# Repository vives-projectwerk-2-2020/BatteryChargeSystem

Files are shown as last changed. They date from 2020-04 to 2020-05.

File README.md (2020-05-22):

# Battery charge system

## Project description

This project is under the MIT license, view it here [MIT License](license.md)

The concept of the this system is to charge some batteries with a solar panel. To supply the whole system.

## Explanation of my roadmap

I first started with the development boards for charging 1 battery with a solar panel. I had 3 boards for use. So I picked the right one. The Adafruit pcb was very interesting for me. And like we all know a Li- Ion battery must be protected when it's fully charged.
After testing everything on the dev pcb's I started designing my own PCB. I used the Eagle software because we're used to it. It wasn't difficult to find the schematics of the dev PCBs. I used those schematics for my base to draw my own PCB.

The duration test of the pcb went very well. I applied a Arduino Uno and a resistor, so i could test if the pcb works fine. There was a current of 50mA through the resistor. If the panel was all day and night outside, one battery was enough. but when the setup wasn't outside, one battery is enough for 2 days. But we need to cover 2 weeks. But this gave me not a correct view of the situation, because we work with sleep modes. And now i have a constant consumption of 50mA. 

The next step was to draw the final schematic of the PCB. Wich is now half the size of the prototype. We made sure the pcb fits in the box we need to use. In this box sit the LoRaWAN antenna and the main pcb with the Nucleo and the batteries too.

## Problems

I hadn't any problems with the PCB draw. Only needed some research for the GND polygoon.

The first problem that came in the game was the Covid-19 outbreak. No more lessons, no more contact with other students. So it wasn't easy to trade the components between some students.

The second problem was that the pcb got down after 3 minutes. When there was no battery attached to the pcb the system worked fine. But once attached, after three minutes, the PCB shuts down.
I did some debugging. The problem was some duplicate functionality. The main IC thought that there was a fully charged battery attached. The MCP 73871 haves all functionality build in that is necessary. So I scrached a wire away so the other ICs (LC05111CMT and MCP73833). The 2 MCP's have the same functionality.
So now the PCB works fine and I could reduce the needed space on the PCB to a minimum.

## Resources

I used the datasheet of the MCP73871 for debugging my PCB. The other documentation was found on the internet. Mostly used for designing my own PCB.

## Battery Charge System

### Description

This panel provide a charge system for charing the batteries via a solar cell.
It seems to be very easy to make this, but actually there comes a lot to play
in the game.
You'll read here how I made this PCB.

#### Develop boards

I first started with some development boards. These PCB's are for sell on the web.
I got 3 boards, so I need to find out witch one was the best for our project.
In this table you'll see the difference between those development boards.

|Feature|Solar Charge Shield V2.2|Adafruit MCP73871|Sparkfun LiPo USB charger|
| ---|:---:|:-----:|:---:|
| **Output disconect** | X  | | |
| **Short circuit protection** | X  | X | |
| **3W output power when connecting battery** | X | | X |
| **Continious charge current**| X  | X | x  |
| **Battery status indication** | X | X | |
| **Micro USB connection** | X | X | X |
| **Load sharing** |  | X | |
| **Temperature monitoring**  |  | X | X |
| **Possible to add extra leds** |  | X |  |
| **Lithium - Polymer batteries** | | X | X |
| **Lithium - Ion batteries** | X | X | X |

I worked together with my classmate Niels to find out with PCB was the best.
We came to a conclusion that the Adafruit board was the best for us.
So the next step was to find oud how it works and how we need to setup the prototype.

##### More information about the development board

##### Specifications

* 3.7V/4.2V Lithium Ion or Lithium Polymer battery charger
* Charge with 5-6V DC, USB or 6V solar panel!
* Automatic charging current tracking for high efficiency use of any wattage
solar panel
* Use any 6V solar panel
* Three color indicator LEDs - Power good, Charging and Done
* Low Battery Indicator (fixed at 3.1V) with LED output on (labeled CHRG)
* Set for 500mA max charge rate, can be adjusted from 50mA up to 1A by soldering
in a resistor
* Will always draw the most current possible from a solar cell- up to the max
charge rate!
* Smart load sharing automatically uses the input power when available, to keep
battery from constantly charging/discharging
* Temperature monitoring of battery by soldering in a 10K NTC thermistor
[thermistor](http://adafru.it/372) (not included) - suggested for outdoor projects
where the battery may get hot (50°C) or cold (0°C).

##### Indicator led's

* The red PWR LED indicates that there is good power connected to the charger.
If this LED is not lit, something is wrong with the power supply
* The orange CHRG LED indicates current charging status. When this LED is lit,
the charger is working to charge up a battery! It also acts as a low battery
indicator (fixed at 3.1V) when no power is connected. So, if you don't have
USB/Solar wired up, when the battery voltage drops below 3.1V, the orange LED
will come on.
* The green DONE LED is pretty easy to understand as well - when it's lit the
battery is charged up! Very handy for when you want to know that everything is done.

##### Extra features

* Load Sharing
* Temperature monitoring
* Adjusting the max charge current
* Adding external LEDs

This was quite easy.
In the picture below you'll see how is set this configuration up.

In the first pic it's the concept of the configuration.

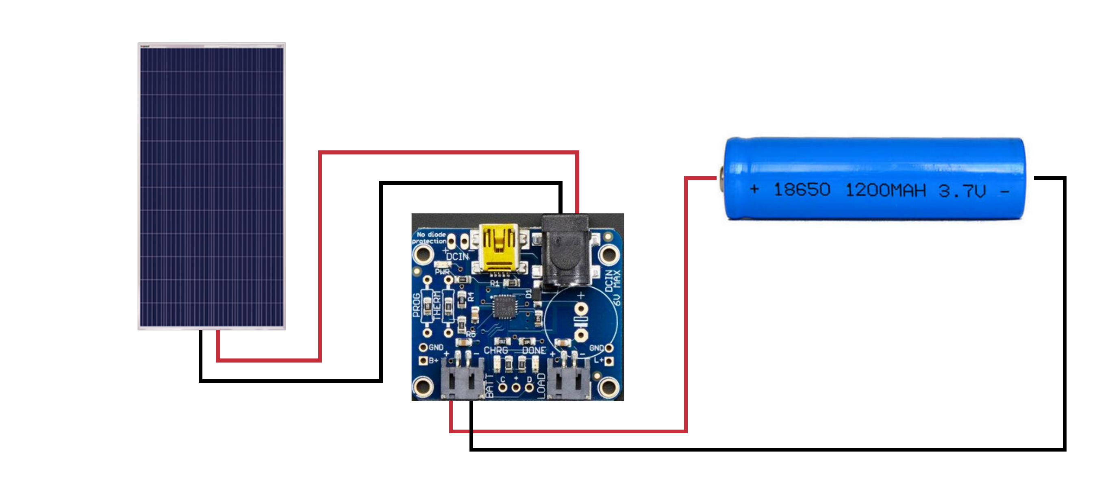
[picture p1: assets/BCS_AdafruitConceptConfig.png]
Concept configuration


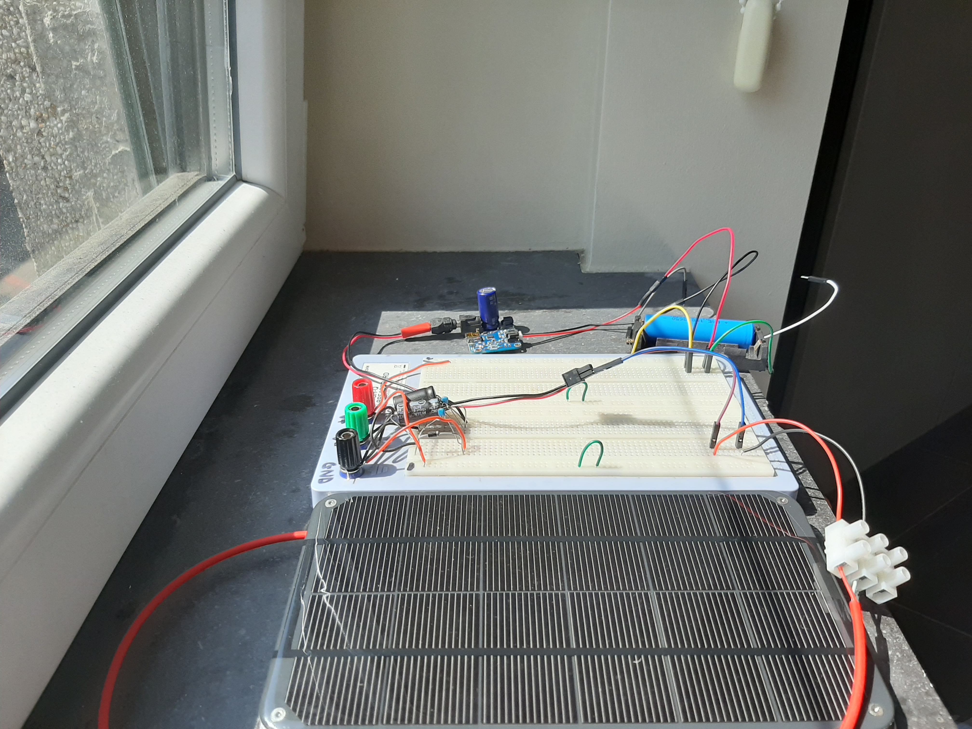
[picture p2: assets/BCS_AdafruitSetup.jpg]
Setup van prototype

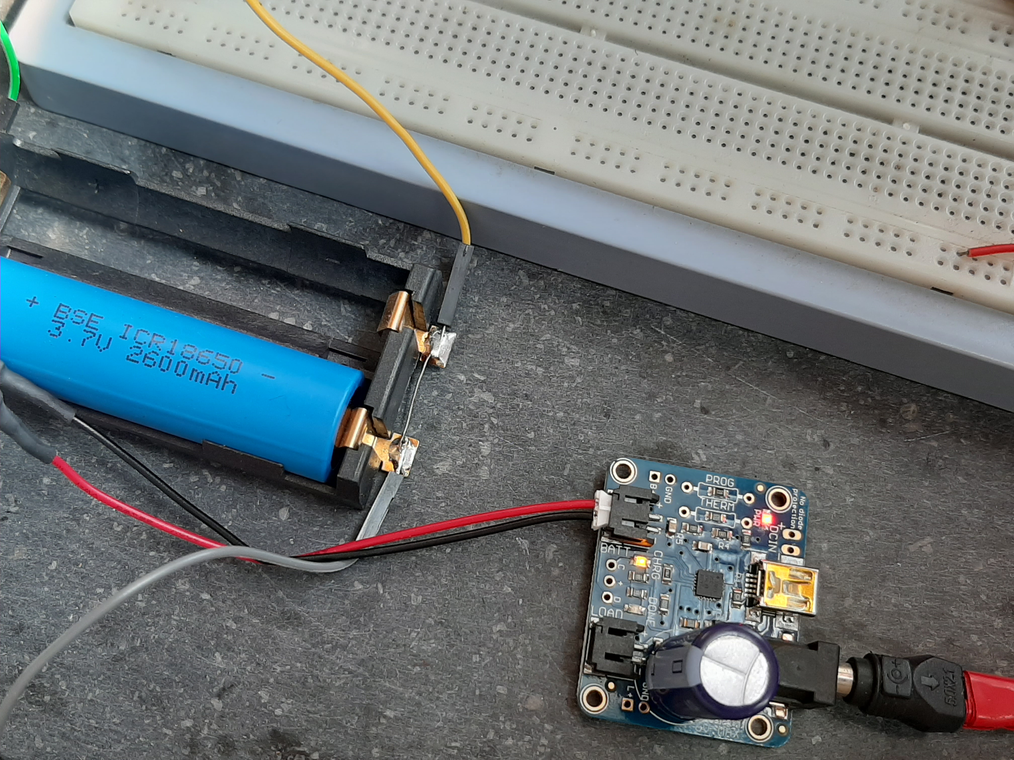
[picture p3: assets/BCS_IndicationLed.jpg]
Indication leds


This system was well tested, so I did some measurements  to see how good it works.
You can see some pictures of the measurements below

##### Charge voltage

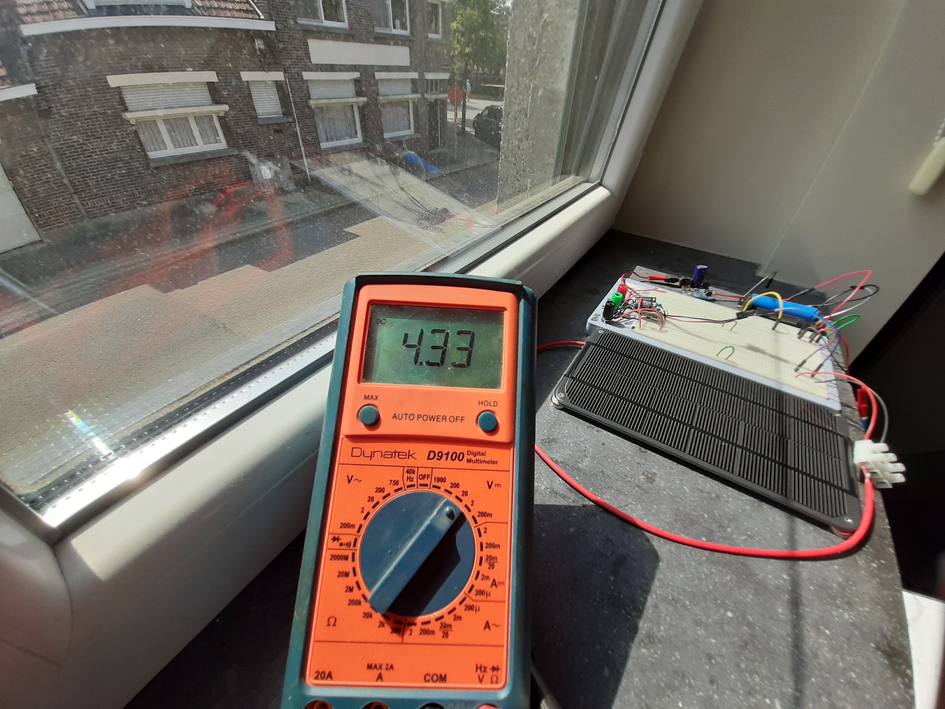
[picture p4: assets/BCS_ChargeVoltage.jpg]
Value of chargevoltage


As we can see, the batteries are supplied with a voltage of 4.3V. A Li-Ion battery
of 3.7V loads until it reaches 4.2V. You can see in the picture of the battery
voltage, that he isn't charged fully. So The charge current is maximum.

##### Charge current

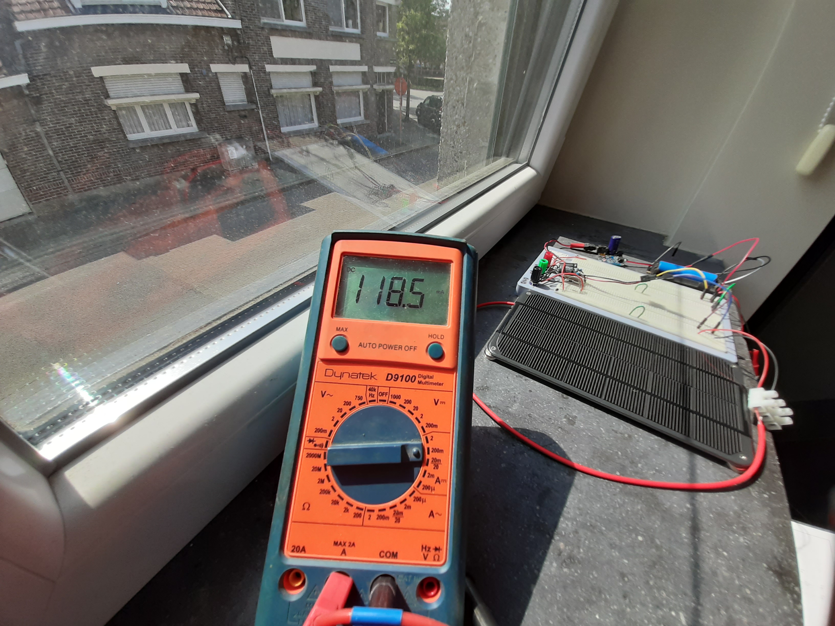
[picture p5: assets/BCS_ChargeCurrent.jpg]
value of charge current


When the battery voltage raises, the charge current will go down. When 4.2V is
reached, the charge current is 0A.
So the current you see on the display, is near maximum.

##### Battery voltage

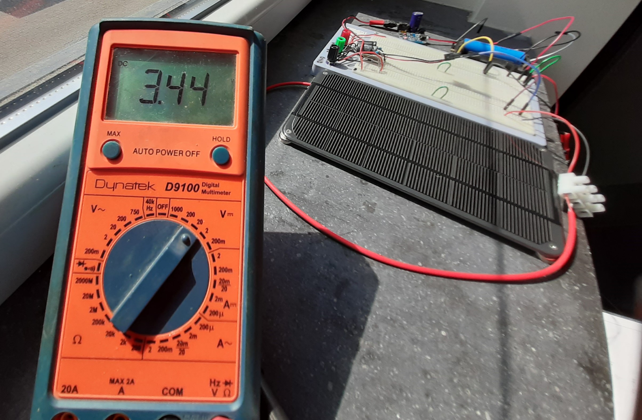
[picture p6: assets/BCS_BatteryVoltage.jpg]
value of battery voltage


The battery voltage is not high, the voltage will go to 4.2V.

##### solar panel voltage

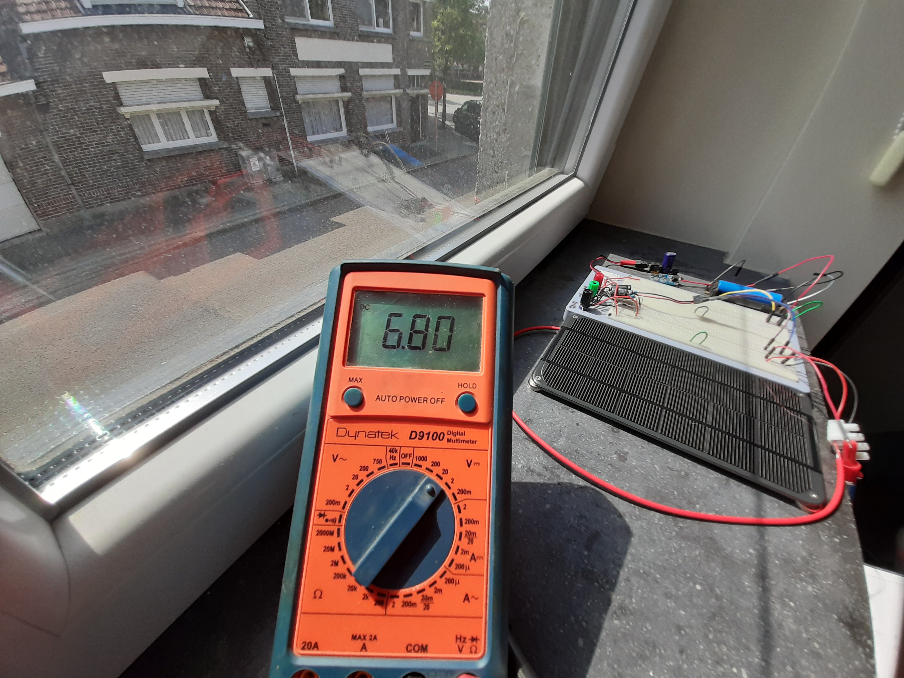
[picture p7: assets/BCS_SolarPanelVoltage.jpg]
value of solar panel voltage


The solar panel provides a voltage of near 7V. This is quite high! In my own
PCB I'll need to protect my main IC from this high voltage.

### Our own design

#### Description of my own design

I used the development boards to look for some inspiration, so I could (easily)
make my own design. I started with a prototype, and I'll explain how this works.

#### Schematic

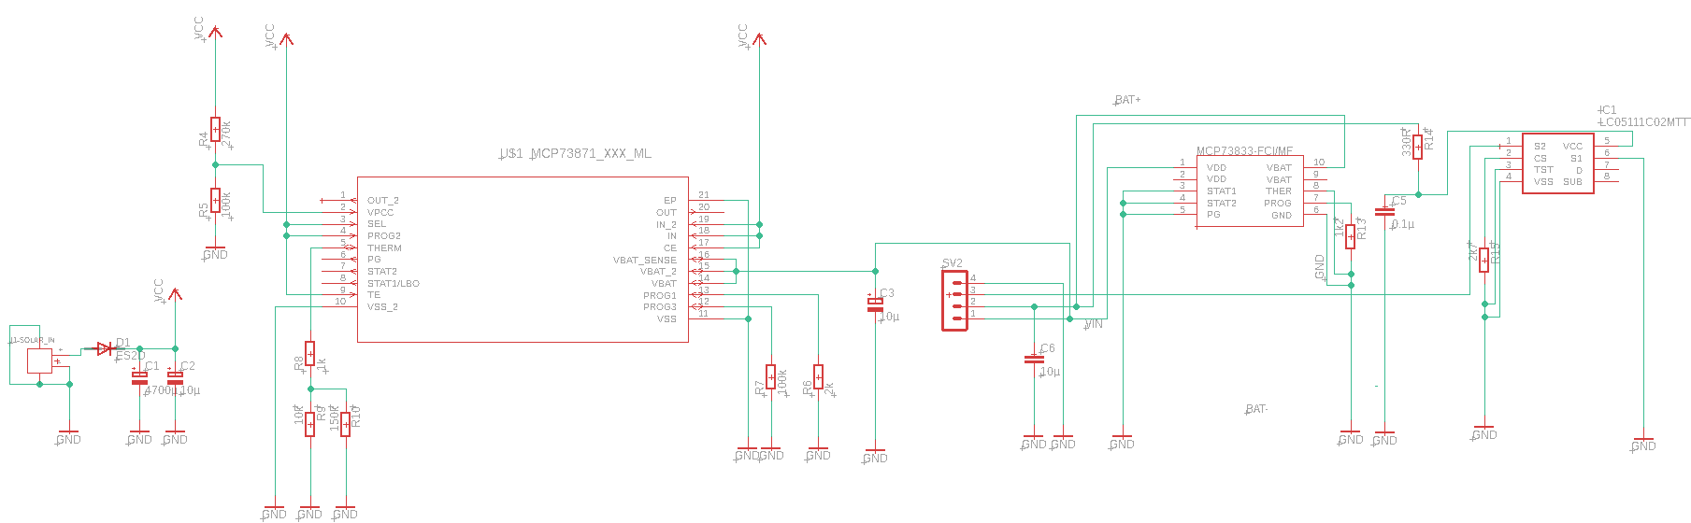
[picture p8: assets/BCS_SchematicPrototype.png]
schematic prototype


##### Description of the schematic

This is the prototype schematic with actually some bugs in it.
The first IC (MCP73871) manages the battery. This was the same IC of the
development board. He'll keep track on the charge current and voltage. When the
battery is charged, the charge current will be 0 because this IC will drop it down.
There is also a possibility to get some information via the PG, STAT1, STAT2 pins.
These aren't provided here, but in the final PCB it does. This IC takes the
voltage from the solar panel and have's an output of 4.3V.

The second IC is a battery management IC too, this will cause problems. You'll
see in the final PCB that this IC is deleted. In first place I thought that it
was necessary to provide a protection circuit for the battery. But the MCP73871
haves already this functionality. So I will discuss my problems later in this
document, and will explain there what went wrong.

The other components are some interfacing for these IC's.

#### Board

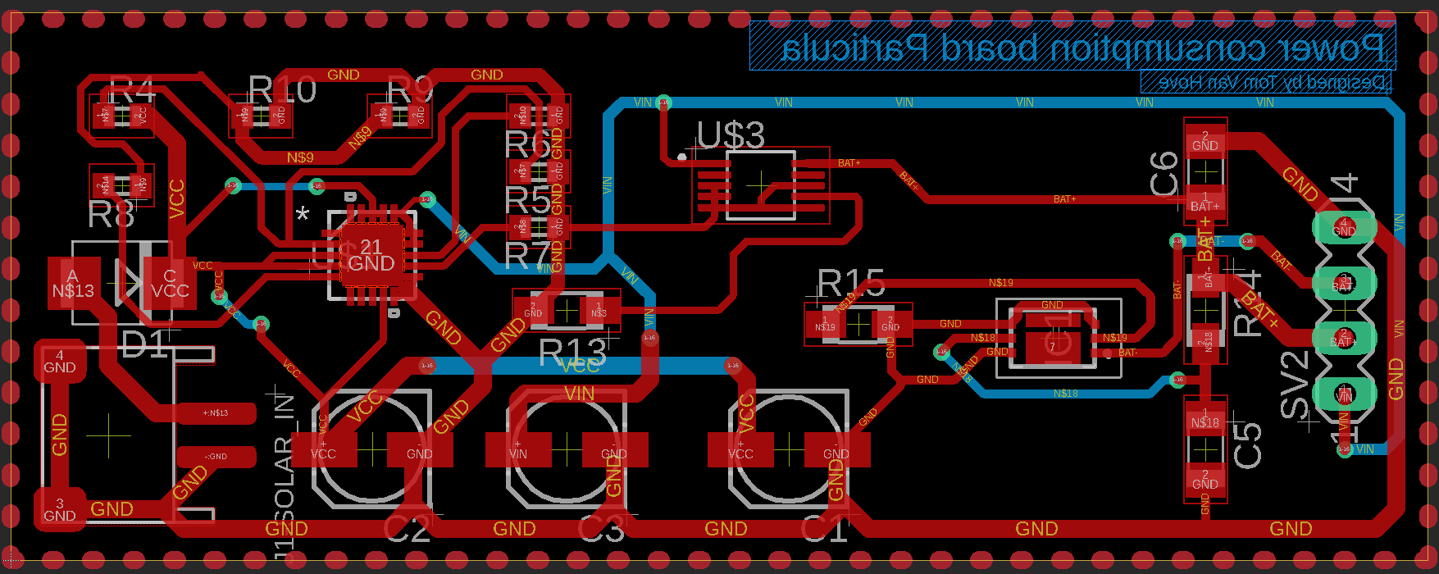
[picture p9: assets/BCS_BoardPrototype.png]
board prototype

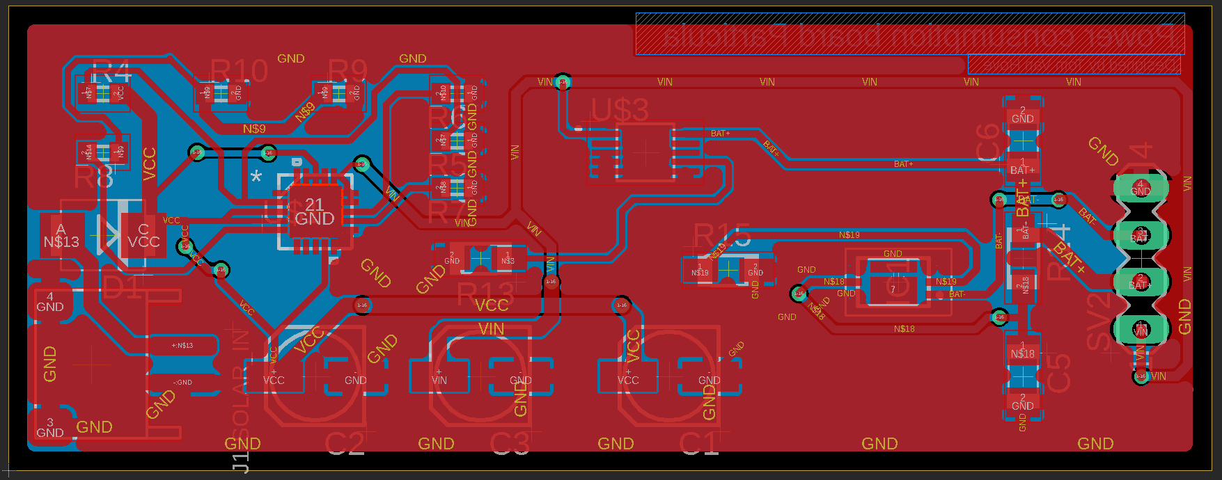
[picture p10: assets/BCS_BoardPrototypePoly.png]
board prototype with polygon


##### Description of the board

The next step was to draw the board. This is quite easy. The first picture is
the schematic witout polygon, the second one is the PCB with polygon. We let
these PCB's made in Japan. Via [JLCPCB](http://JLCPCB.com). Then we bought our
components by Farnell for fast shipping. When we got all components and boards,
we could start soldering. Me and my colleagues are used to solder, so this
wasn't any problem for us.

In this pic you'll see the unsoldered and soldered PCB

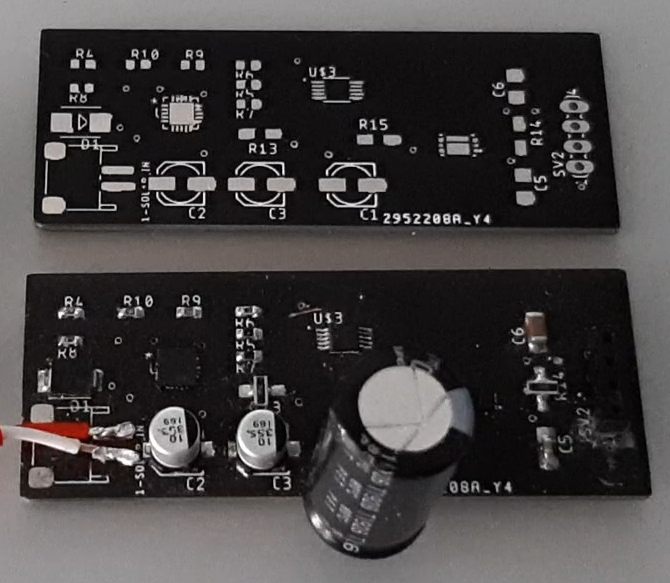
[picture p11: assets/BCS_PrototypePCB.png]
manufactured pcb


#### Description of the final design

You can find here the link to the GitHub repo of the schematic, board and partlist.
[GitHub repo final design](https://github.com/vives-projectwerk-2-2020/FinalSolarChargeSystem)

#### Final Schematic

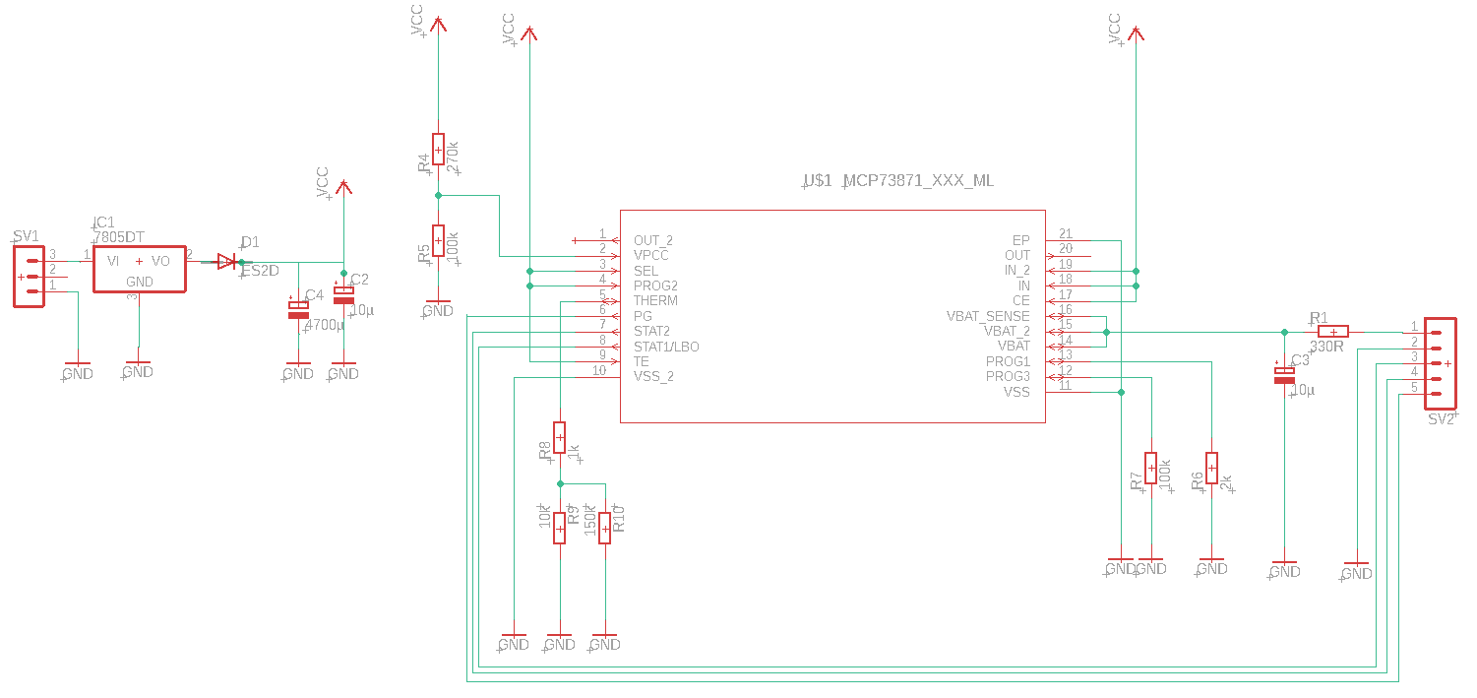
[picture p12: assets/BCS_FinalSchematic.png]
final schematic


##### Description of the final schematic

As you can see here, the other IC's are removed. This because they have the same
functionality as the MCP73871. I placed a voltage regulator before the IC, this
is because you can have a max voltage of 6V on the IC, and the solar panel
provides 6+V.
Here I brought the STAT1, STAT2 and PG pins outside, so we can manage the battery
on the Nucleo.
This PCB will fit on the main PCB (See Niels his documents).

#### Final Board

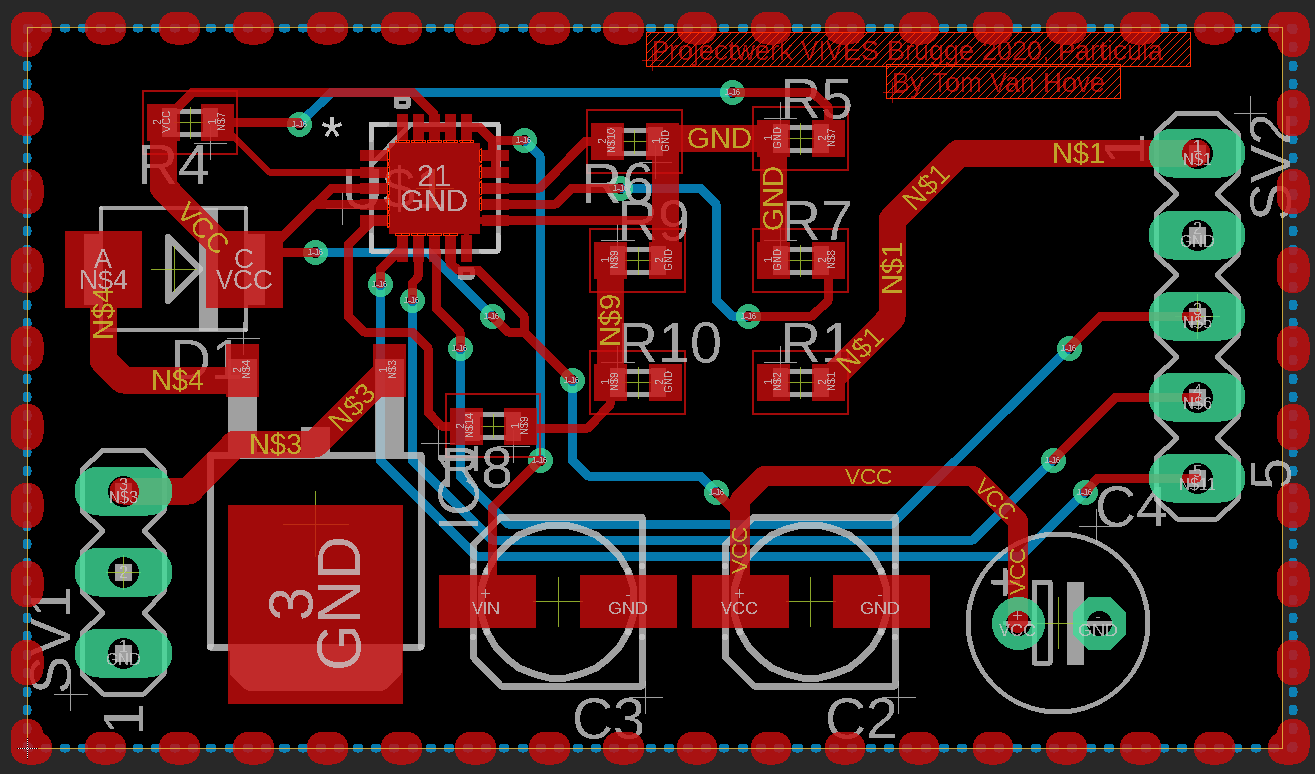
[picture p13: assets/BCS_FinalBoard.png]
final board

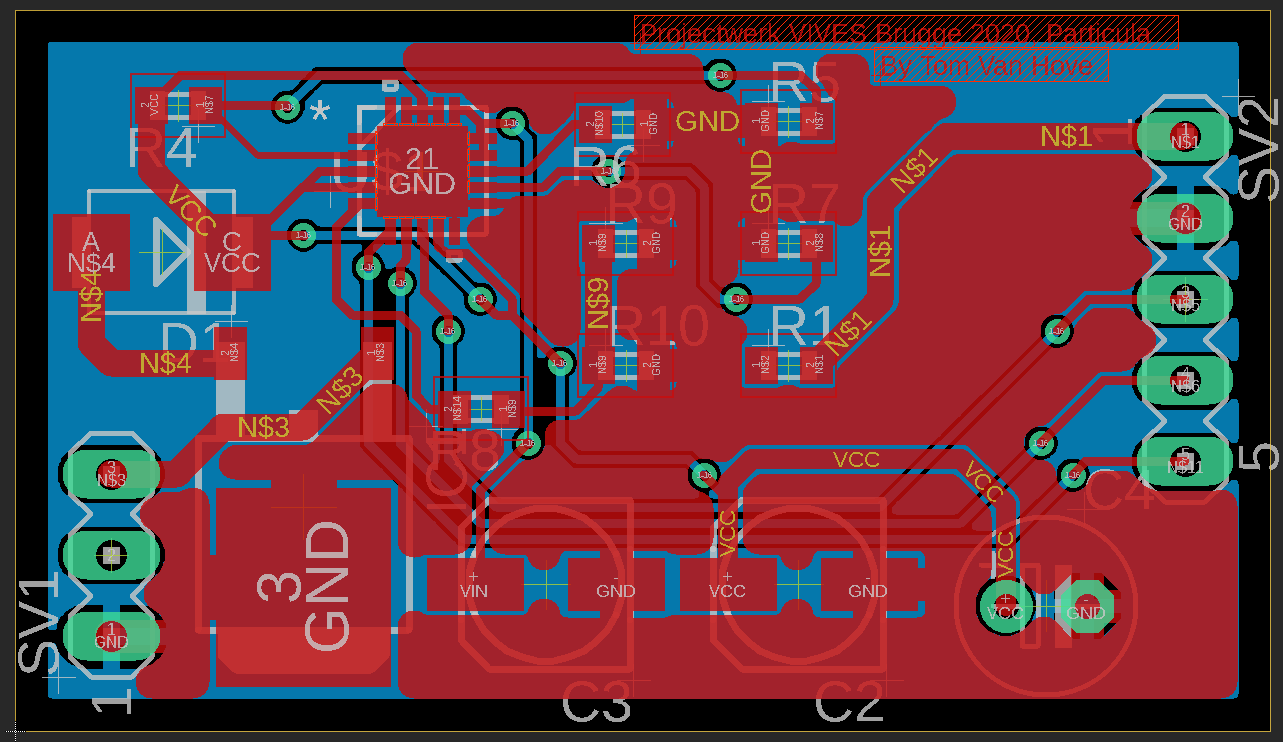
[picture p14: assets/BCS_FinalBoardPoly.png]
final board with polygon


##### Description of the final Board

There is not so much to tell about it, here to, just draw the wires.
We couldn't order these PCB's because of the COVID-19 pandemic.

### Tests

When we had the prototype PCB, we soldered them, and then we need to test if they
really work.

When I tested the PCB without a battery connected, the charge voltage was 4.2V.
This was really good, that worked. But when I attached a battery, the system
falls down after 2 minutes. So is started looking for the problem. And as you
could see, there is a difference between the prototype PCB and the final PCB.
1 IC in stead of 3. This was because the MCP73871 have same functionality of all
those other IC's. So I don't need them. What was the source of the problem? Well,
the MCP73871 checked the battery status, but he actually checked the MCP83833
and this IC wasn't a battery, so the MCP73871 shuts down because he thought that
te battery was fully charged.
When scratching away the wire tot the MCP83833, the PCB worked like it need to be!

After this, is started a duration test. I made a setup with a Arduino UNO to
have a current taken away from the battery.
The charge PCB was still connected to the batteries.
The setup have been outside for 3 - 4 weeks, day and night.
In the picture below, you'll see the setup I made.

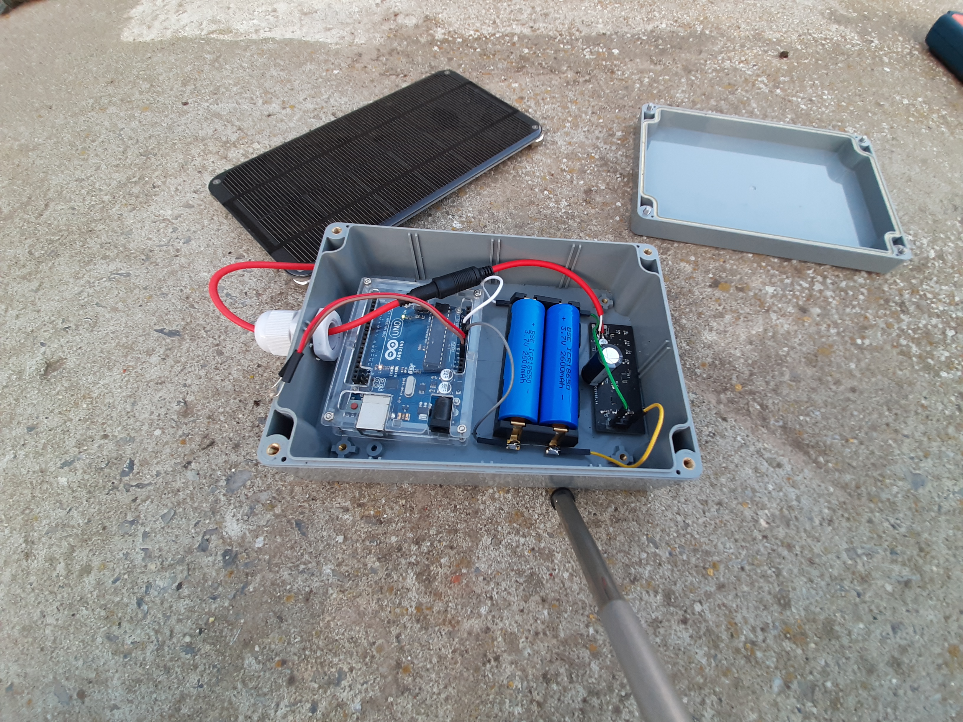
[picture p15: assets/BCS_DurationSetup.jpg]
duration setup

outdoor config

I went daily for a measurement of the PCB. I measured the voltage of the solar
panel, IC input, IC output, battery voltage and charge current.
|Measurement | Value |
|---|---|
|Solar panel |6,8V |
|IC input |5V |
|IC output |4,2V |
|Battery voltage|3V - 4.2V |
|charge current |0mA - 100mA |

The charge current depends on the weather. When it is a nice day, you'll reach
higher current measurements. The charge current depends on the battery voltage
too. When the battery voltage reaches 4.2V, the current will drop town to 0.

How I did these measurements, can be found in my Youtube video.

### Links

* [MCP73871 datasheet](http://adafru.it/aMO)
* [Fritzing object in Adafruit Fritzing library](http://adafru.it/aP3)
* [EagleCAD Board / Layout & Schematic files on Github](http://adafru.it/aMP)

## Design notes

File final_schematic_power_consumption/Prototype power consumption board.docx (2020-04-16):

# Prototype power consumption board

# Schematic

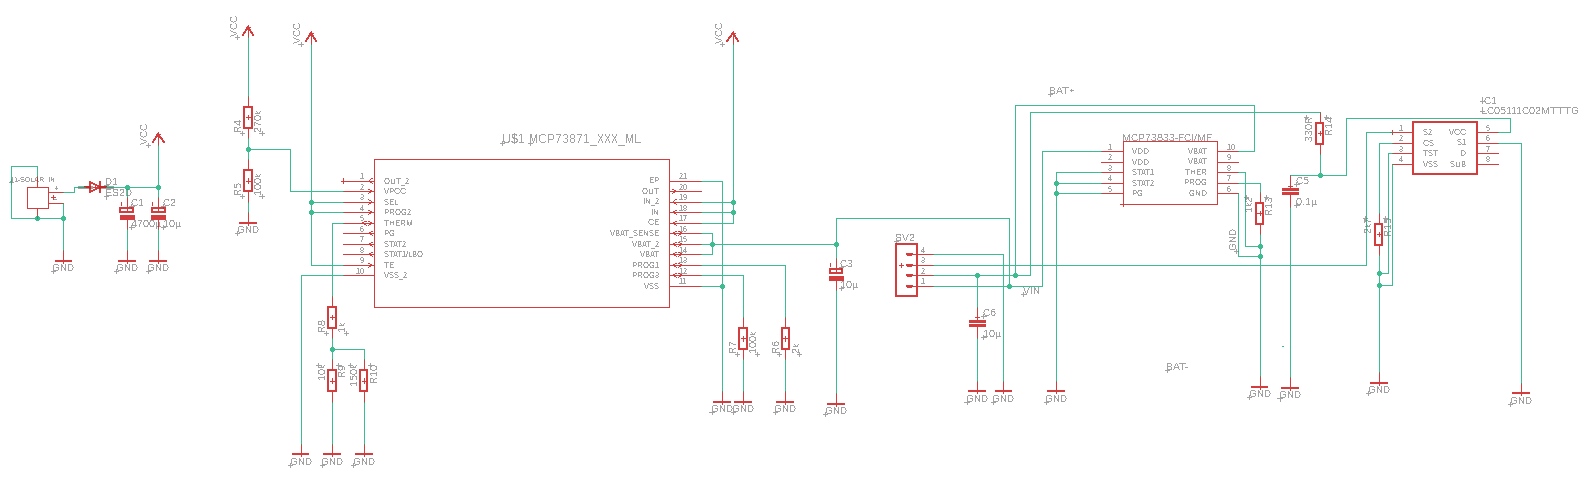
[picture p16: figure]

# Board

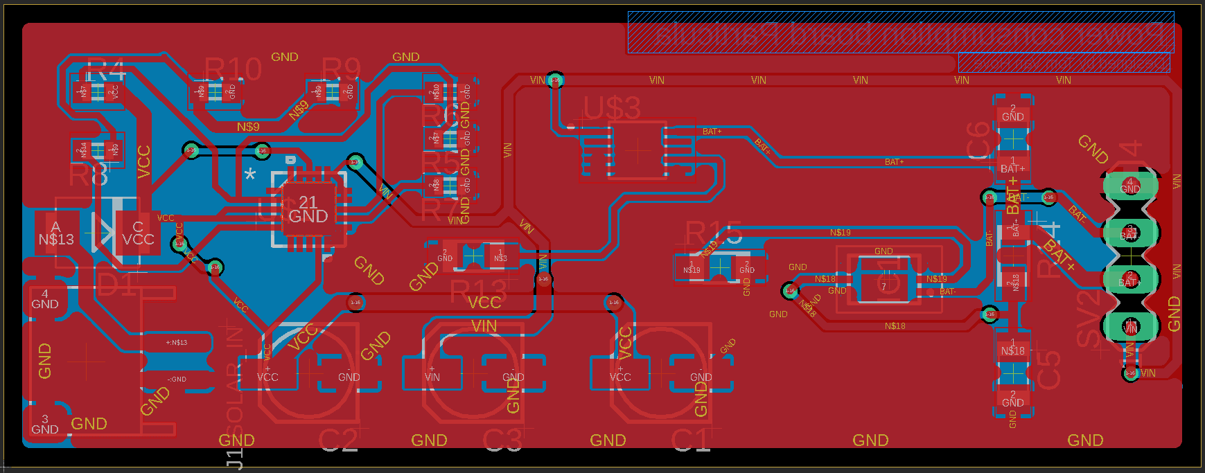
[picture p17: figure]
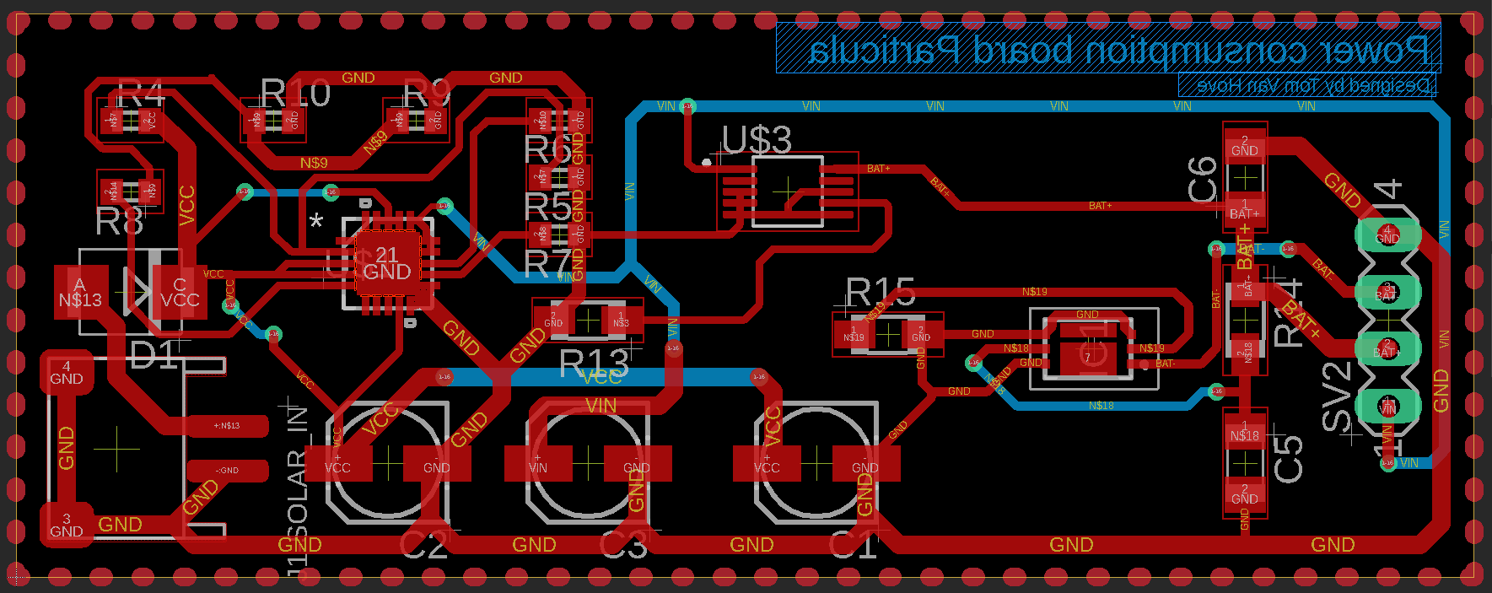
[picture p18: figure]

# Partlist FARNELL

Part | Value | FARNELL NR
C1 | 4700Âµ | 2346507
C2 | 10Âµ | 9697012
C3 | 10Âµ | 9697012
C5 | 0.1Âµ | 2211074
C6 | 10Âµ | 1907353
D1 | ES2D | 1467491
IC1 | LC05111C02MTTTG | 2728216
J1-SOLAR_IN
R4 | 270k | 2447313
R5 | 100k | 1692517
R6 | 2k | 2447319
R7 | 100k | 1692517
R8 | 1k | 9238484
R9 | 10k | 2861870
R10 | 150k | 2447254
R13 | 1k2 | 3254959
R14 | 330R | 3254970
R15 | 2k7 | 3254908
SV2 | | 1667510
U$1 | MCP73871_XXX_ML | 1642489
U$3 | MCP73833-FCI/MF | 1605576

# Recommandations

## PCB order

The ordering of the PCBs went very well. JLCPCB is an good site with fast shipping. The quality of them are very nice!

## Component order

We worked with Farnell because their fast shipping. Everything went well, all components are in stock and they were delivered very soon. But in multiple packets.

## Soldering

The soldering went great. We used only SMD. With the soldering station of VIVES it went very good! We used very small components because of available space on our PCB and we need to fit 3 PCBs in 1 single box with batteries.

I can make my PCB more smaller and that’s the next step after testing and debugging.

One mistake we made with the component order, we didn’t order an FLUX CLEANER so our PCB is a bit dirty right now. The final PCB will be clean.

## Testing

I tested the PCB only with a solarpanell and without batteries. And I got a voltage measure of 4.2V what is very nice!

After that step I loaded some batteries and the PCB stop charging when the batteries are 3.7V loaded. I’m not sure that that would be enough for feeding the NUCLEO and other hardware. Maybe I can place 2 batteries serial, but my pcb won’t work anymore. I can place them parallel too, for more capacity.

After charging the batteries, I discharged them with an ventilator (just a consumer, it could be anything). The ventilator worked 22 hours, non stop.

After this I recharged 1 battery …

TODO

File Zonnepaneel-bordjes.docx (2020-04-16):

Solar Charger Shield V2.2

1. Features:
- Output Disconnect
- Short circuit protection
- 3W Output Power when connecting battery
- Continuous Charge Current Up to 900mA
- Battery status indication ( Red : Charging , Green: Charged )
- Micro-USB Connector
2. Specification
- Battery input voltage: 3.0~4.5V
- USB input voltage: 4.75~5.25V
- Solar input voltage: 4.8~6V
- Maximum Output Power(with battery): 3W(600mA@5V)
- Ripple voltage: <100mV @ 500mA
- Dimensions: 68*53mm
3. Applications
- Wireless sensor unit
- Solar charge
- Tweet-a-volt-arduino
4. Caution
- The solar charger shield is designed to protect any potential short circuit. However care must be taken to avoid any such situations.
- The solar shield should not be operated at voltages greater than 5V

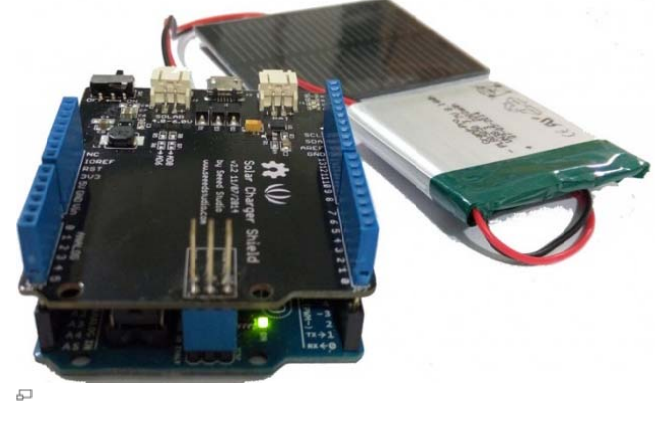
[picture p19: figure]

USB, DC & Solar Lipoly Charger

1. Specifications
- 3.7V/4.2V Lithium Ion or Lithium Polymer battery charger
- Charge with 5-6V DC, USB or 6V solar panel!
- Automatic charging current tracking for high efficiency use of any wattage solar panel
- Use any 6V solar panel
- Three color indicator LEDs - Power good, Charging and Done
- Low Battery Indicator (fixed at 3.1V) with LED output on (labeled CHRG)
- Set for 500mA max charge rate, can be adjusted from 50mA up to 1A by soldering in a resistor
- Will always draw the most current possible from a solar cell- up to the max charge rate!
- Smart load sharing automatically uses the input power when available, to keep battery from constantly charging/discharging
- Temperature monitoring of battery by soldering in a 10K NTC thermistor (http://adafru.it/372) (not included) - suggested for outdoor projects where the battery may get hot (50°C) or cold (0°C).
2. Installing the Capacitor
- This capacitor is necessary to stabilize the panel a little, and since we're going to charge with a lot of current, the capacitor needs to be pretty big.
3. USB & DC Charging
- Of course, sometimes is just really dark out and you can't solar charger, so there's a USB port on the board as well.
- Use any mini-B cable to plug in and charge.
4. Indicator LEDs
- The red PWR LED indicates that there is good power connected to the charger. If this LED is not lit, something is wrong with the power supply
- The orange CHRG LED indicates current charging status. When this LED is lit, the charger is working to charge up a battery! It also acts as a low battery indicator (fixed at 3.1V) when no power is connected. So, if you don't have USB/Solar wired up, when the battery voltage drops below 3.1V, the orange LED will come on.
- The green DONE LED is pretty easy to understand as well - when it's lit the battery is charged up! Very handy for when you want to know that everything is done.
5. Extra features
- Load Sharing
- Temperature monitoring
- Adjusting the max charge current
- Adding external LEDs
6. Files
- MCP73871 datasheet (http://adafru.it/aMO)
- Fritzing object in Adafruit Fritzing library (http://adafru.it/aP3)
- EagleCAD Board / Layout & Schematic files on Github (http://adafru.it/aMP)

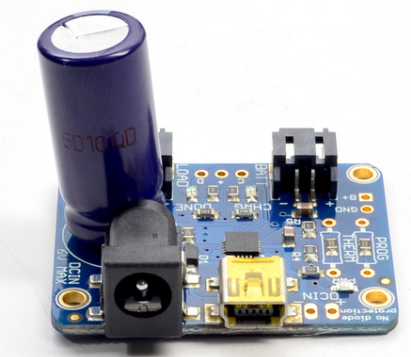
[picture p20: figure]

Single-cell LiPo MPPT charger

1. Features
- Input Supply Voltage Regulation Loop for Peak Power Tracking in (MPPT) Solar Applications
- Wide Input Voltage Range: 4.95V to 32V (40V Abs Max)
- Programmable Charge Rate Up to 2A
- User Selectable Termination: C/10 or On-Board Termination Timer
- Resistor Programmable Float Voltage Up to 14.4V Accommodates Li-Ion/Polymer, LiFePO4, SLA Chemistries
- No VIN Blocking Diode Required for Battery Voltages ≤ 4.2V
- 1MHz Fixed Frequency
- 0.5% Float Voltage Reference Accuracy
- 5% Charge Current Accuracy
- 2.5% C/10 Detection Accuracy
- Binary-Coded Open-Collector Status Pins
- 3mm × 3mm DFN12 or MSOP-12 Packages
2. Description
- The LT®3652 is a complete monolithic step-down battery charger that operates over a 4.95V to 32V input voltage range.
- The LT3652 provides a constant-current/ constant-voltage charge characteristic, with maximum charge current externally programmable up to 2A.
- The charger employs a 3.3V fl oat voltage feedback reference, so any desired battery fl oat voltage up to 14.4V can be programmed with a resistor divider.
- The LT3652 employs an input voltage regulation loop, which reduces charge current if the input voltage falls below a programmed level, set with a resistor divider.
- When the LT3652 is powered by a solar panel, the input regulation loop is used to maintain the panel at peak output power.
- The LT3652 can be confi gured to terminate charging when charge current falls below 1/10 of the programmed maximum (C/10).
- Once charging is terminated, the LT3652 enters a low-current (85μA) standby mode.
- An auto-recharge feature starts a new charging cycle if the battery voltage falls 2.5% below the programmed float voltage.
- An auto-recharge feature starts a new charging cycle if the battery voltage falls 2.5% below the programmed fl oat voltage.
- The LT3652 also contains a programmable safety timer, used to terminate charging after a desired time is reached.
- This allows top-off charging at currents less than C/10
3. Absolute maximum ratings

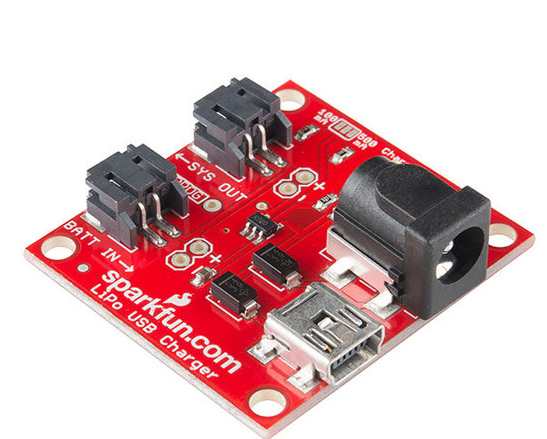
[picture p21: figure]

Differences

| Solar Charger Shield V2.2 | USB, DC & Solar Lipoly Charger | Single-cell LiPo MPPT charger
Output Disconnect | X
Short circuit protection | X | x
3W Output Power when connecting battery | X | | x
Continuous Charge Current Up to 500mA -900mA | X | X (when soldering extra resistor) | x
Battery status indication ( Red : Charging , Green: Charged ) | X | x
Micro-USB Connector | X | x | x
Load sharing | | x
Temperature monitoring | | x | x
Posibillity to ad external LEDs | | x
Lithium-Polymer batteries | | x | X
Lithium-Ion batteries | x | | x

Datasheets

https://cdn-learn.adafruit.com/downloads/pdf/usb-dc-and-solar-lipoly-charger.pdf

https://static.chipdip.ru/lib/164/DOC001164903.pdf

http://cdn.sparkfun.com/datasheets/Prototyping/LT3652.pdf

https://www.distrelec.be/Web/Downloads/_t/ds/Adafruit_390_eng_tds.pdf?pid=30091214

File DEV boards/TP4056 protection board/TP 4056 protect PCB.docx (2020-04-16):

# TP 4056 - protect PCB

# Specificaties

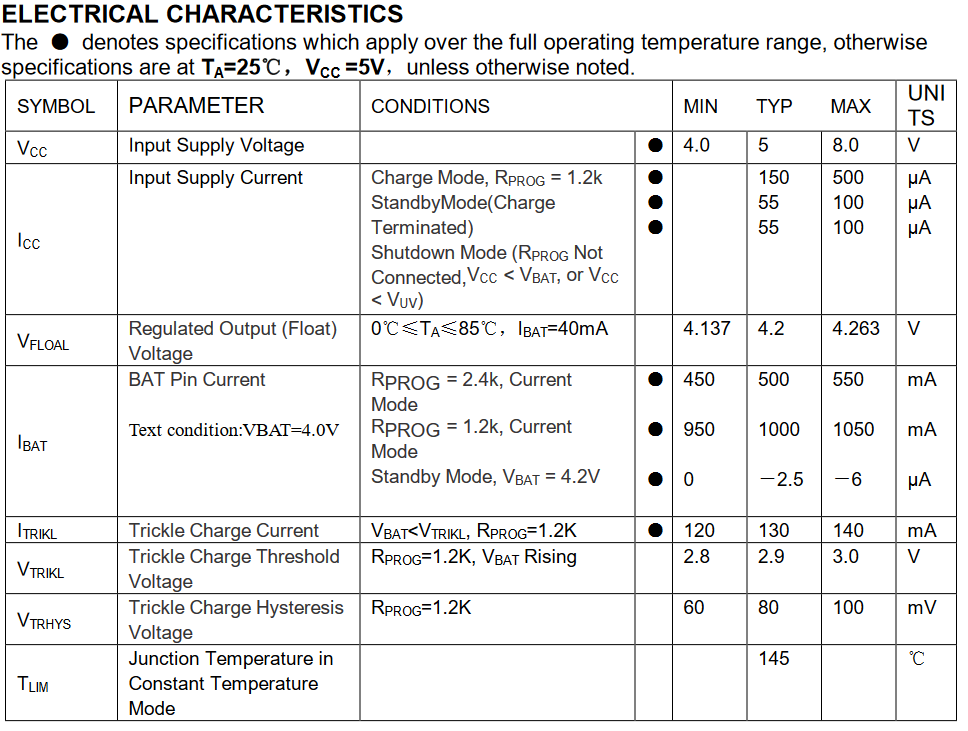
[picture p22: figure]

# Doel

Bescherming batterij tegen overspanning. Als de batterij vol geladen is, dan zal deze schakeling de kring onderbreken.

# Werking

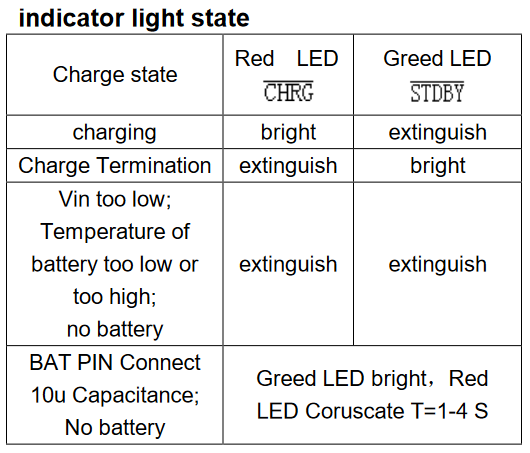
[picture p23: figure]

Als de batterij aan het opladen is, dan zal de rode led gaan branden op de PCB. Als de batterij volgeladen is dan gaat de groene led oplichten.

Stel er hangt geen batterij aan, of de ingangsspanning is te laag, temperatuur te hoog of te laag is.

Bij het opladen met het zonnepanneel, hebben we een laadstroom van rond de 50mA. Kiezen we voor een USB gevoede lading, spreken we over een laadstroom van rond de 150mA. Resultaat, via USB zal de batterij veel sneller geladen kunnen worden.

Als de spanning van de batterij stijgt, dan zal de laadstroom dalen, tot op 0, waarbij de groene led dan gaat branden.

# Schematische voorstelling

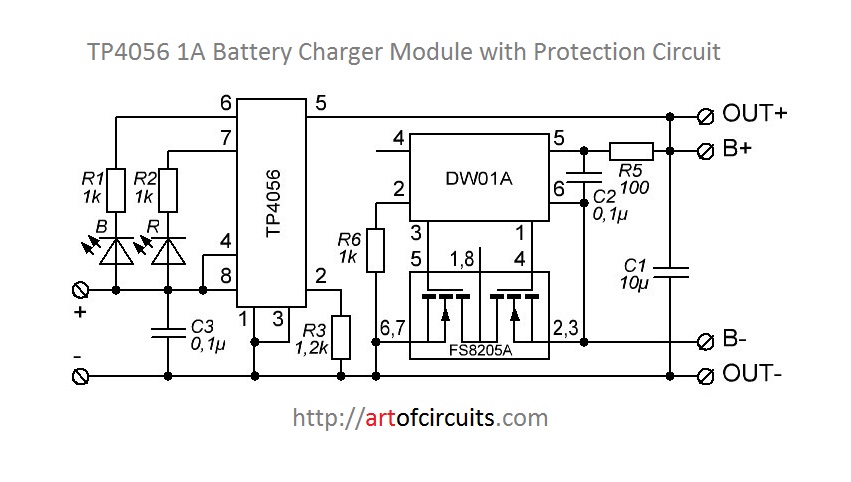
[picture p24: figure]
Schema

## DW01A

https://www.ic-fortune.com/upload/Download/DW01x-DS-17_EN_53550.pdf

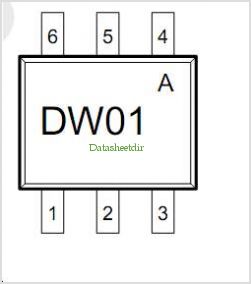
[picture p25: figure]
DW01A pinout,Pin out

## TP4056

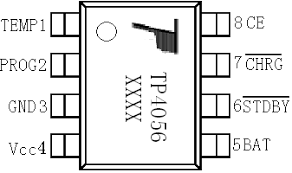
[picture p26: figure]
C:\Users\Tom\AppData\Local\Microsoft\Windows\INetCache\Content.MSO\A78E72FA.tmp

## FS8205A

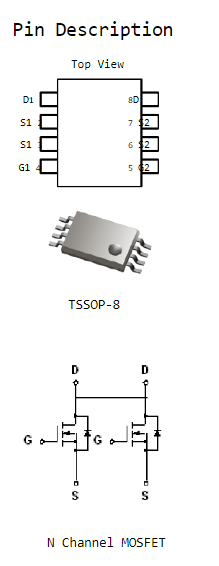
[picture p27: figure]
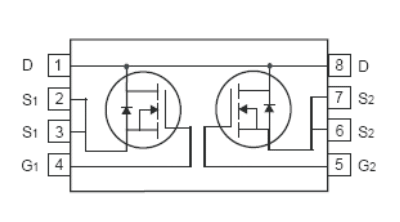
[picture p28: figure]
Afbeeldingsresultaat voor 8205a pinout
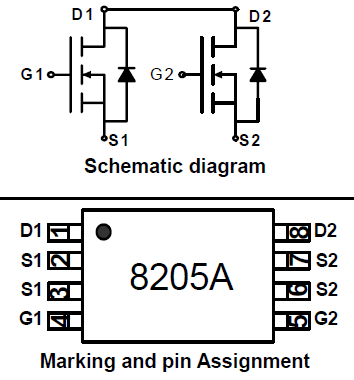
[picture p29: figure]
Afbeeldingsresultaat voor 8205a pinout

# Aansluiting

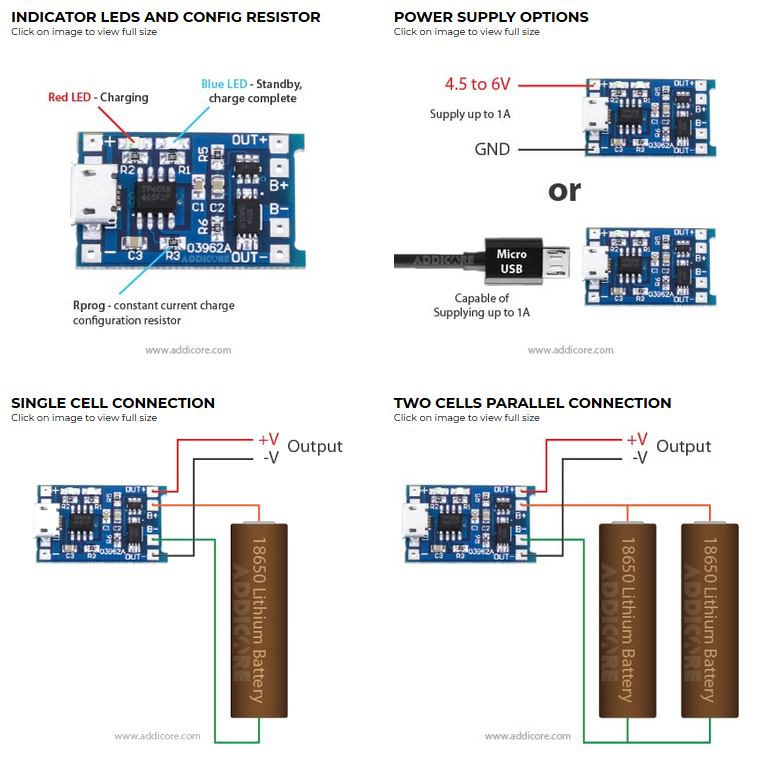
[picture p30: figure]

# Interessante links

https://dlnmh9ip6v2uc.cloudfront.net/datasheets/Prototyping/TP4056.pdf

https://www.makerlab-electronics.com/product/tp4056-5v-1a-lithium-battery-charging-with-protection-micro-usb/

https://www.addicore.com/TP4056-Charger-and-Protection-Module-p/ad310.htm

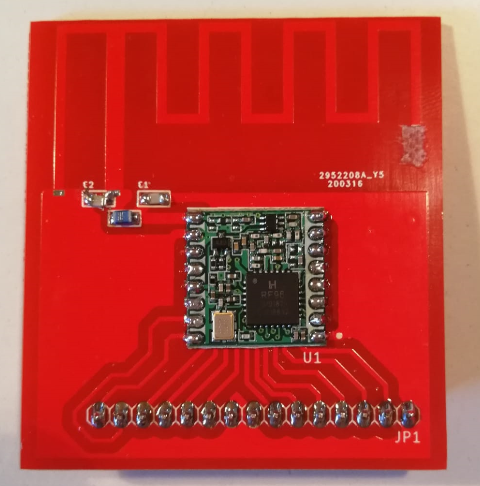
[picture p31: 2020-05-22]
assets/Antenna_board.png

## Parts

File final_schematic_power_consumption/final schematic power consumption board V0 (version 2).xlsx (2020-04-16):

Part | Value | Device | Package | Description
C1 | 4700Âµ | CPOL-EU153CLV-0505 | 153CLV-0505 | POLARIZED CAPACITOR, European symbol | 2346507 | 3 | https://be.farnell.com/rubycon/16pk4700mefc12-5x25/cap-4700-f-16v-20/dp/2346507
C2 | 10Âµ | CPOL-EU153CLV-0505 | 153CLV-0505 | POLARIZED CAPACITOR, European symbol | 9697012 |  | https://be.farnell.com/panasonic/eee1va100sr/cap-10-f-35v-radial-smd/dp/9697012
C3 | 10Âµ | CPOL-EU153CLV-0505 | 153CLV-0505 | POLARIZED CAPACITOR, European symbol | 9697012 |  | https://be.farnell.com/panasonic/eee1va100sr/cap-10-f-35v-radial-smd/dp/9697012
C5 | 0.1Âµ | C-EUC1206 | C1206 | CAPACITOR, European symbol | 2211074 |  | https://be.farnell.com/tdk/cga5l2c0g1h104j160aa/cap-0-1-f-50v-5-c0g-np0-1206/dp/2211074
C6 | 10Âµ | C-EUC1206 | C1206 | CAPACITOR, European symbol | 1907353 |  | https://be.farnell.com/tdk/c3216x7r1c106k160ac/cap-10-f-16v-10-x7r-1206/dp/1907353
D1 | ES2D | ES2D | SMB | DIODE | 1467491 |  | https://be.farnell.com/on-semiconductor/es2d/diode-fast-2a-200v-smd-do-214/dp/1467491?st=ES2D
IC1 | LC05111C02MTTTG | LC05111C02MTTTG | LC05111C02MTTTG | Battery Management 1 CELL LIB PROTECTION IC | 2728216 |  | https://be.farnell.com/on-semiconductor/lc05111c02mtttg/over-current-protector-li-ion/dp/2728216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
J1-SOLAR_IN |  | CONN-HEADER-SMD-PH-SIDE-(2P-2.0MM) | HW2-SMD-2.0-90D | 320110026
R4 | 270k | R-EU_R0603 | R0603 | RESISTOR, European symbol | 2447313 |  | https://be.farnell.com/multicomp/mcwr06x2703ftl/res-270k-1-0-1w-thick-film/dp/2447313
R5 | 100k | R-EU_R0603 | R0603 | RESISTOR, European symbol | 1692517 |  | https://be.farnell.com/vishay/crcw0603100kjnea/res-100k-5-0-1w-0603-thick-film/dp/1692517
R6 | 2k | R-EU_R0603 | R0603 | RESISTOR, European symbol | 2447319 |  | https://be.farnell.com/multicomp/mcwr06x2001ftl/res-2k-1-0-1w-0603-thick-film/dp/2447319
R7 | 100k | R-EU_R0603 | R0603 | RESISTOR, European symbol | 1692517 |  | https://be.farnell.com/vishay/crcw0603100kjnea/res-100k-5-0-1w-0603-thick-film/dp/1692517
R8 | 1k | R-EU_R0603 | R0603 | RESISTOR, European symbol | 9238484 |  | https://be.farnell.com/yageo/rc0603fr-071kl/res-1k-1-0-1w-0603-thick-film/dp/9238484
R9 | 10k | R-EU_R0603 | R0603 | RESISTOR, European symbol | 2861870 |  | https://be.farnell.com/te-connectivity/crgcq0603j10k/res-10k-5-0603-thick-film/dp/2861870
R10 | 150k | R-EU_R0603 | R0603 | RESISTOR, European symbol | 2447254 |  | https://be.farnell.com/multicomp/mcwr06x1503ftl/res-150k-1-0-1w-thick-film/dp/2447254
R13 | 1k2 | R-EU_R1206W | R1206W | RESISTOR, European symbol | 3254959 |  | https://be.farnell.com/rohm/ltr18ezpj122/res-1k2-5-0-75w-1206-thick-film/dp/3254959
R14 | 330R | R-EU_R1206W | R1206W | RESISTOR, European symbol | 3254970 |  | https://be.farnell.com/rohm/ltr18ezpj331/res-330r-5-0-75w-1206-thick-film/dp/3254970
R15 | 2k7 | R-EU_R1206W | R1206W | RESISTOR, European symbol | 3254908 |  | https://be.farnell.com/rohm/ltr18ezpf2701/res-2k7-1-0-75w-1206-thick-film/dp/3254908
SV2 |  | MA04-1 | MA04-1 | PIN HEADER | 1667510 |  | https://be.farnell.com/samtec/ces-104-01-t-s/receptacle-2-54mm-single-4way/dp/1667510
U$1 | MCP73871_XXX_ML | MCP73871_XXX_ML | QFN20_4X4MC |  | 1642489 |  | https://be.farnell.com/microchip/mcp73871-2cci-ml/ic-battery-management-cont-qfn20/dp/1642489?st=MCP73871
U$3 | MCP73833-FCI/MF | MCP73833-FCI/MF | SOP50P490X110-10N |  | 1605576 |  | https://be.farnell.com/microchip/mcp73833-fci-un/ic-charge-control-li-ion-1a-msop/dp/1605576?st=MCP73833

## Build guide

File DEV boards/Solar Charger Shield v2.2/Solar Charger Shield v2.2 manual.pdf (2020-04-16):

# Solar Charger Shield V2.2

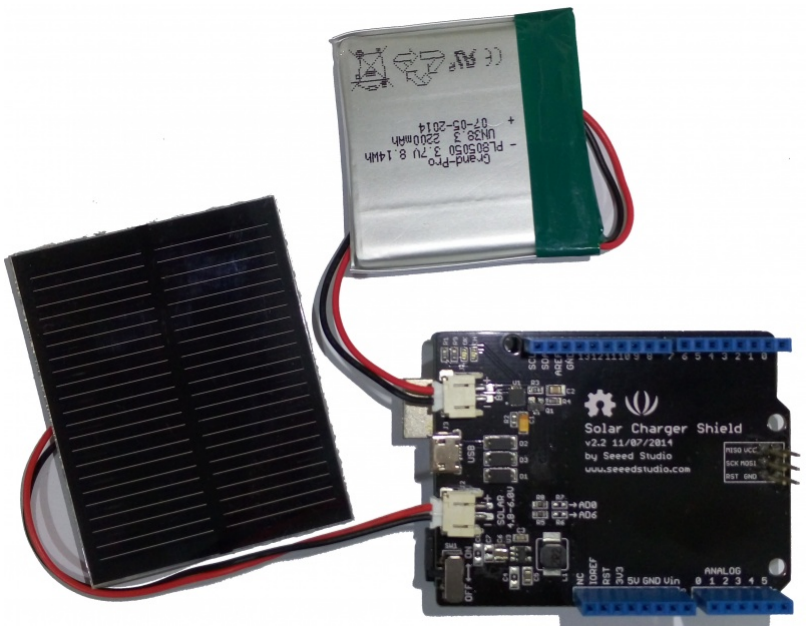
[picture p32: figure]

The solar charger is a stackable shield to Arduino compatible platforms, enables adaptive battery power and act as energy harvester for in-field charging. You may use various batteries that has the voltage of 3.0V-4.2V to shift up for 5V output, or put on Li-ion battery and solar panel to form an autonomous sensor unit. The maximum current provided by the board can get up to 600mA. An usb connector is also useful to charge the battery.

## Features

- Output Disconnect
- Short circuit protection
- 3W Output Power when connecting battery
- Continuous Charge Current Up to 900mA
- Battery status indication ( Red : Charging , Green: Charged )
- Micro-USB Connector

## Specification

- Battery input voltage: 3.0~4.5V
- USB input voltage: 4.75~5.25V
- Solar input voltage: 4.8~6V
- Maximum Output Power(with battery): 3W(600mA@5V)

- Ripple voltage：<100mV @ 500mA
- Dimensions: 68*53mm

## Applications

- Wireless sensor unit
- Solar charge
- Tweet-a-volt-arduino

## Information on use of Solar panels for charging

1) The solar charger shield produces charges under sunlight and light from filament bulbs. Its function is more effective in the former than in the latter. Solar panels require invisible radiations namely ultraviolet and infrared radiations for producing current.
2) In order to test the system under filament bulb, hold the solar panel at a distance, less than 20cm(< 0.5 feet). However, the charging may not be effective under filament bulbs.
3) Place the solar panel at an angle such that the maximum amount of sunlight is incident on it.
4) Protect the solar panel from excessive exposure to water/water vapors. This may oxidize the surface of the solar panel and reduce its performance.
5) The Solar panel usually comes with a protective transparent sheet of cover. Remove the transparent plastic sheet for better performance of the solar panel.
6) Protect the surface of the solar panel from scratches

## Caution

1) The solar charger shield is designed to protect any potential short circuit. However care must be taken to avoid any such situations.
2) The solar shield should not be operated at voltages greater than 5V

## Usage

1) Connect the Solar panel and the Li-Pol battery in their designated places as shown in the figure below:

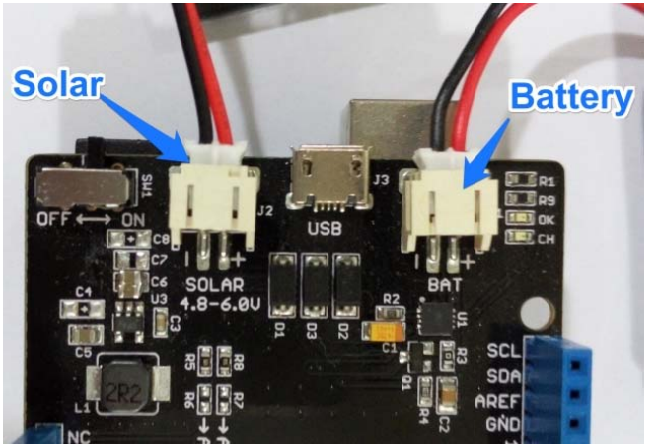
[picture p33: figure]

Solar

2) Pl
solar
3) En

r_Charger_

lace the sola
r panels" sec

nsure that th

Shield_v2.2

ar under sun
ction

he charging

2_inputs.jpg

nlight or fila

(Red) light

ament bulbs

t glows as s

as mention

hown in the

ned in the "I

e figure belo

Information

ow:

for using

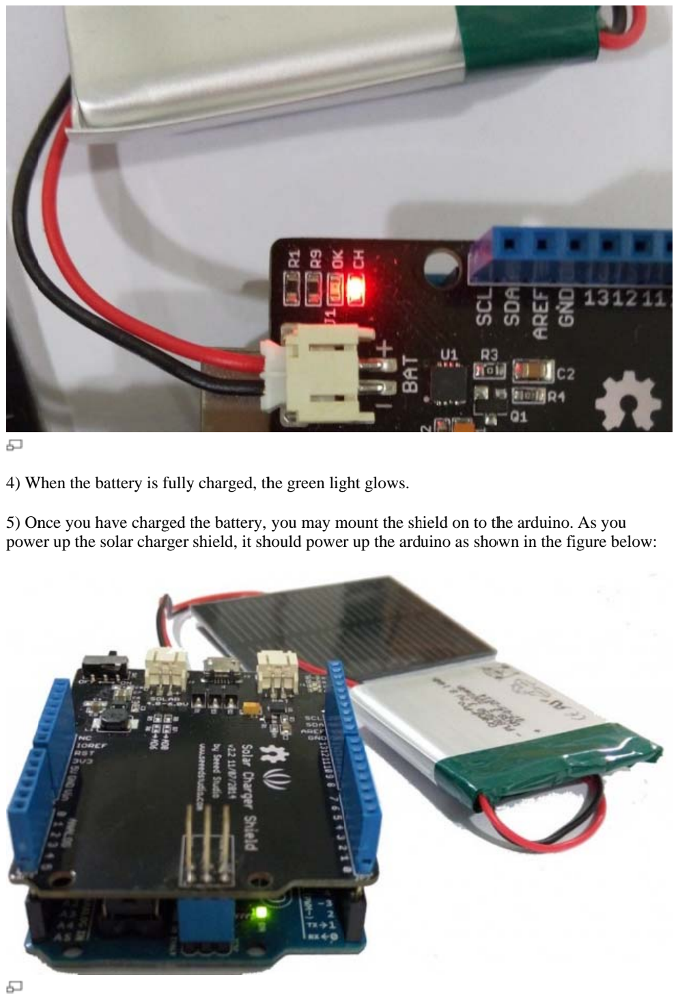
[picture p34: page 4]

4) W
5) On
powe

When the bat

nce you hav
er up the so

ttery is fully

ve charged t
lar charger

charged, th

he battery,
shield, it sh

e green lig

you may m
hould power

ght glows.

mount the sh
r up the ard

hield on to th
uino as show

he arduino.
own in the fi

As you
gure below:

## Tes

Shor

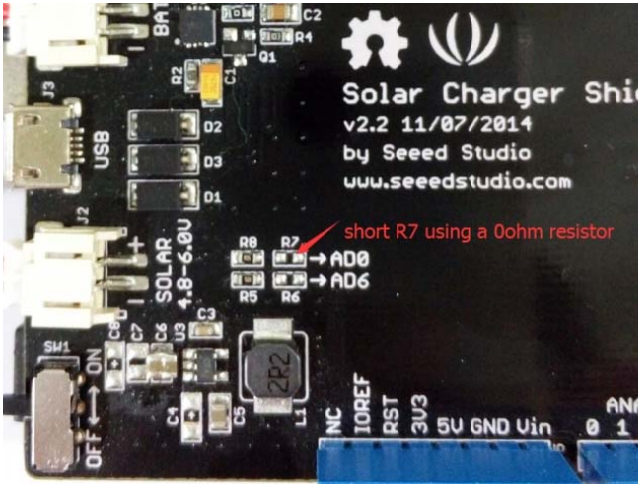
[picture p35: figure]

Img

Prog

You

/*
Sol lar charge | er shield | voltage m measuremen | nt example | e. Connect | t VBAT pin | n to analo | og
pin | A0.
The e pin meas | sures 2.0 | V when no ot under d | direct exp | posre to s | sunlight a | and 5V whe | n
expo osed to su | unlight.

Thi

*/

// T These cons | stants won | n't change | e. They'r | re used to | • give nam | mes
// t to the pin | ns used:
cons st int ana | alogInPin | | = A0; // / Analog i | input pin | | that the | VBAT pin | is
atta ached to

## sting th

rt R7 using a

Solar_Char

gramming

can measur

is example

## he solar

a 0ohm resi

rger_Shield_

g Example

re the voltag

e code is

## shield w

istor as show

_v2.2_short

e

ge of Batter

in the pu

## with a s

wn in the fig

tR7.jpg

ry using the

ublic doma

## simple a

gure:

following e

ain.

## arduino

example:

## o progr

am

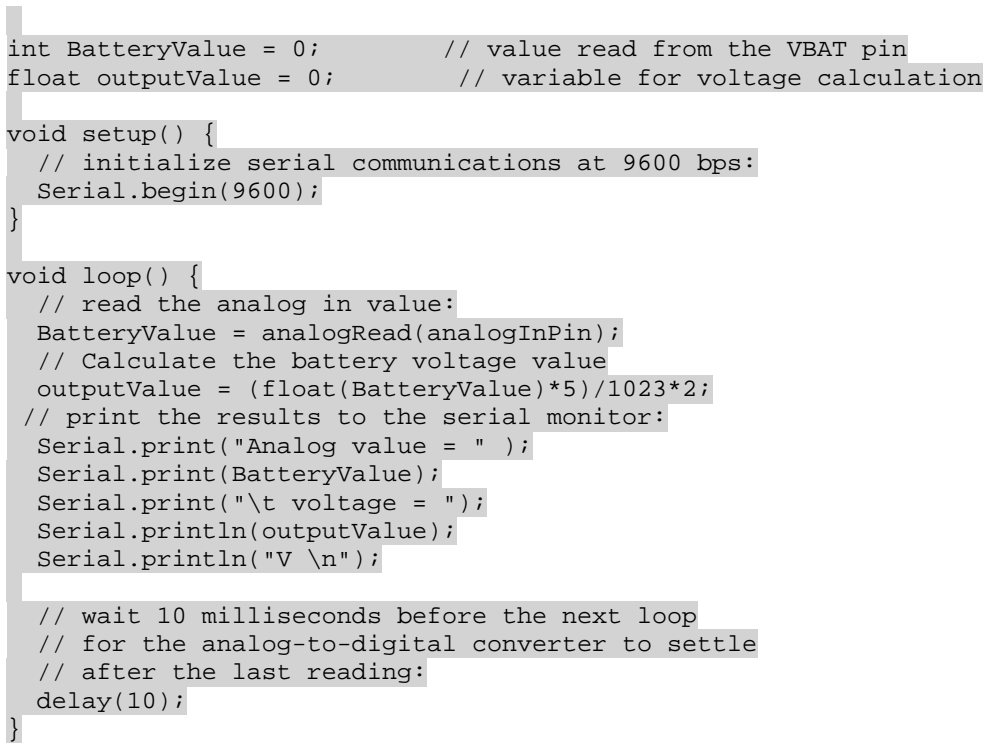
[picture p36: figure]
void setup() {; Serial.begin(9600);; void loop() { // read the analog in value: BatteryValue = analogRead(analogInPin); // Calculate the battery voltage value; Serial.print("Analog value = " ); Serial.print(BatteryValue); Serial.print("\t voltage = "); Serial.println(outputValue); Serial.println("V \n");; // after the last reading: delay(10);

int BatteryValue = 0; | // value read from the VBAT pin
float outputValue = 0; | // variable for voltage calculation

// initialize serial communications at 9600 bps:

outputValue = (float(BatteryValue)*5)/1023*2; // print the results to the serial monitor:

// wait 10 milliseconds before the next loop // for the analog-to-digital converter to settle

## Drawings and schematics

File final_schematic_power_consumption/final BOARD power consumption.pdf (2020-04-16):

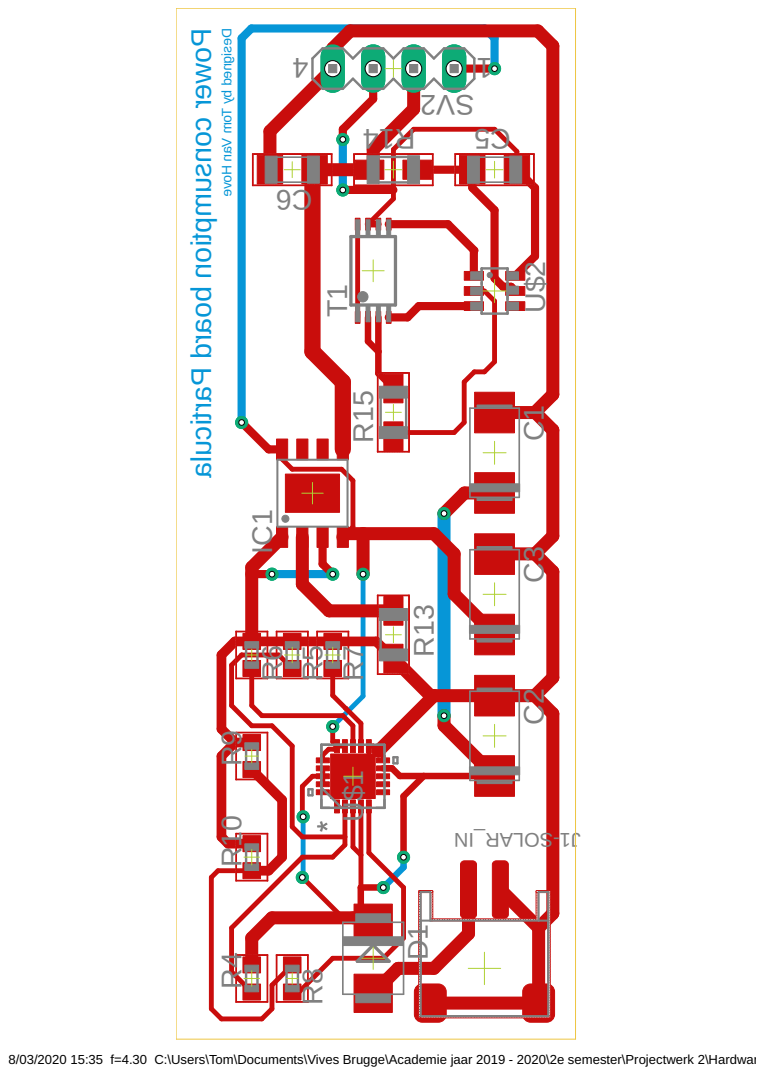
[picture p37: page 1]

8/03/2020 15:35 f=4.30 C:\Users\Tom\Documents\Vives Brugge\Academie jaar 2019 - 2020\2e semester\Projectwerk 2\Hardware_Prototype\final_schematic_power_consumption\final schematic power consumption board.brd

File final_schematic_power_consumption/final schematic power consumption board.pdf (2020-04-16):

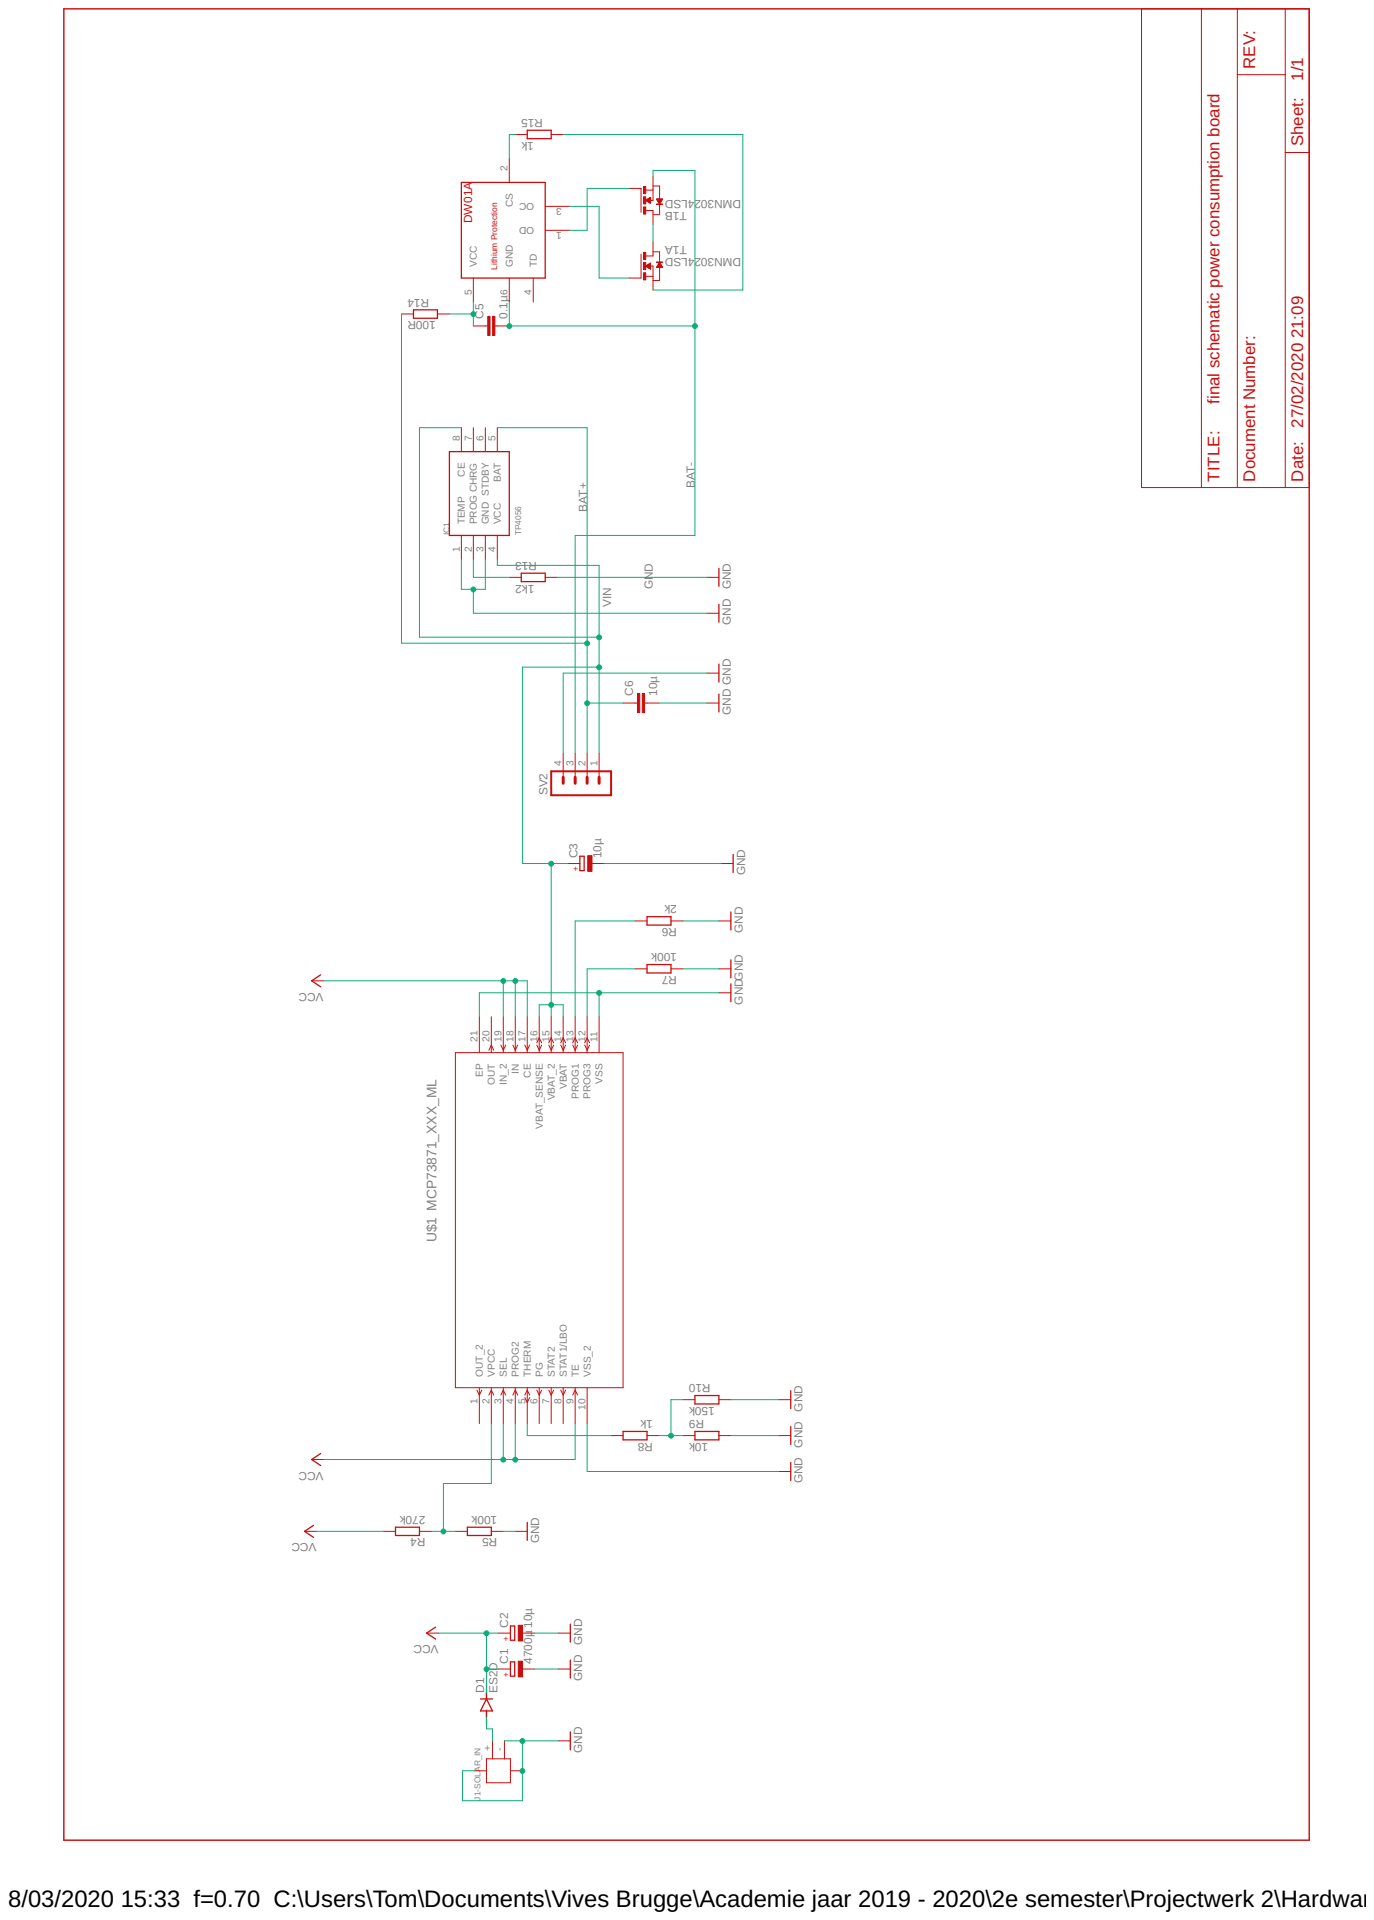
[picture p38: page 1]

Date: Sheet: REV: TITLE: Document Number: 27/02/2020 21:09 1/1

final schematic power consumption board

GND GND GND GND GND

8/03/2020 15:33 f=0.70 C:\Users\Tom\Documents\Vives Brugge\Academie jaar 2019 - 2020\2e semester\Projectwerk 2\Hardware_Prototype\final_schematic_power_consumption\final schematic power consumption board.sch (Sheet: 1/1)

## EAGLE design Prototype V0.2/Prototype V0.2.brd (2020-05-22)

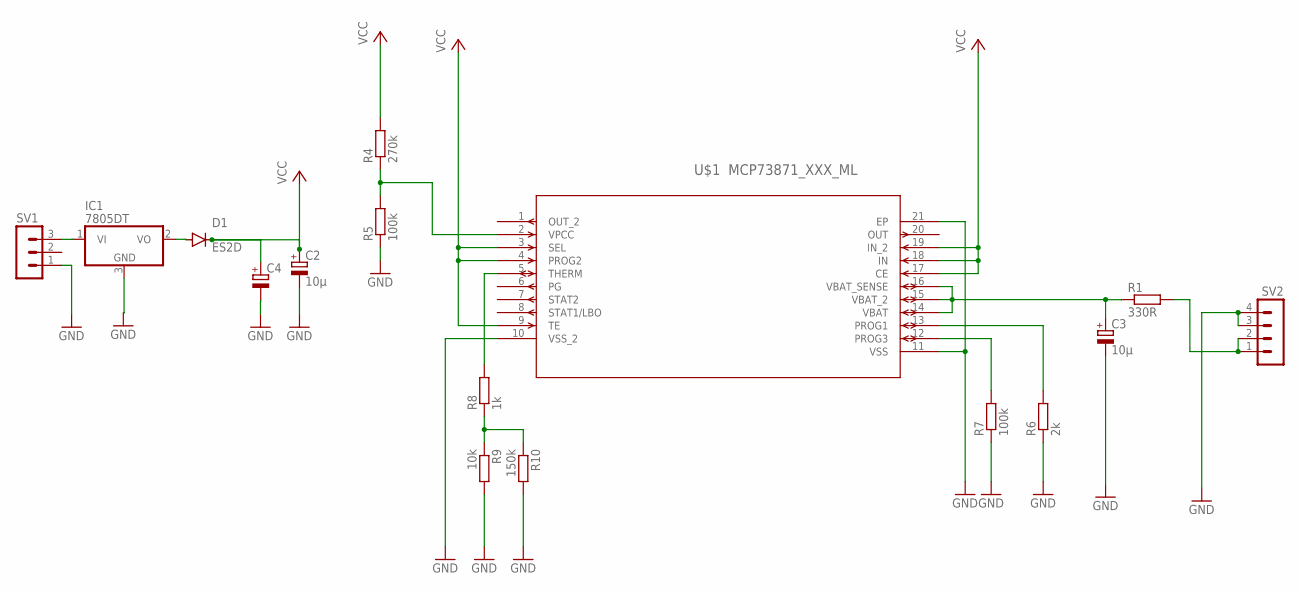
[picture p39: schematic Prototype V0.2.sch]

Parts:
C2, C3: 10µ; 153CLV-0505
C4: CPOL-EUE2.5-6; E2,5-6
D1: ES2D; SMB
IC1: 7805DT; TO252
R1: 330R; R0603
R4: 270k; R0603
R5, R7: 100k; R0603
R6: 2k; R0603
R8: 1k; R0603
R9: 10k; R0603
R10: 150k; R0603
SV1: MA03-1
SV2: MA04-1
U$1: MCP73871_XXX_ML; QFN20_4X4MC

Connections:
GND: C2.-, C3.-, C4.-, IC1.3 (GND), R5.1, R6.1, R7.1, R9.2, R10.2, SV1.1, SV2.3, SV2.4, U$1.10 (VSS_2), U$1.11 (VSS), U$1.21 (EP)
unnamed: R1.2, SV2.1, SV2.2
unnamed: IC1.1 (VI), SV1.3
unnamed: D1.A, IC1.2 (VO)
unnamed: R4.1, R5.2, U$1.2 (VPCC)
unnamed: R7.2, U$1.12 (PROG3)
unnamed: R8.1, R9.1, R10.1
unnamed: R6.2, U$1.13 (PROG1)
unnamed: R8.2, U$1.5 (THERM)
VCC: C2.+, C4.+, D1.C, R4.2, U$1.3 (SEL), U$1.4 (PROG2), U$1.9 (TE), U$1.17 (CE), U$1.18 (IN), U$1.19 (IN_2)
VIN: C3.+, U$1.14 (VBAT), U$1.15 (VBAT_2), U$1.16 (VBAT_SENSE)

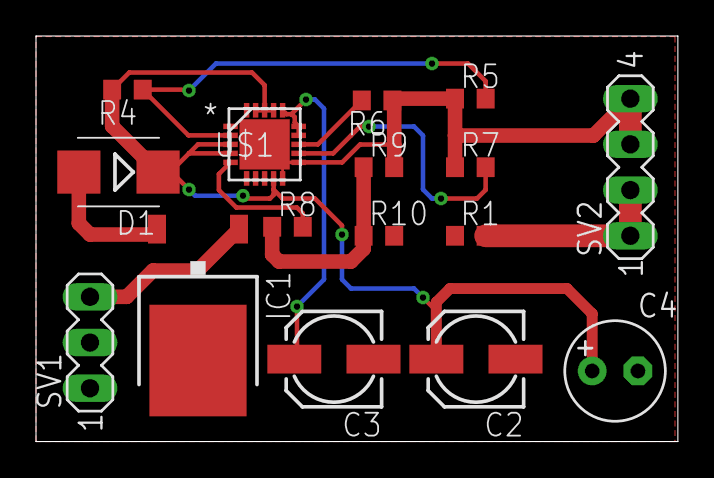
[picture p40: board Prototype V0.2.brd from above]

Board: 2 copper layers, 35.7 x 22.5 mm, 16 parts (0 on the bottom side), 11 nets.

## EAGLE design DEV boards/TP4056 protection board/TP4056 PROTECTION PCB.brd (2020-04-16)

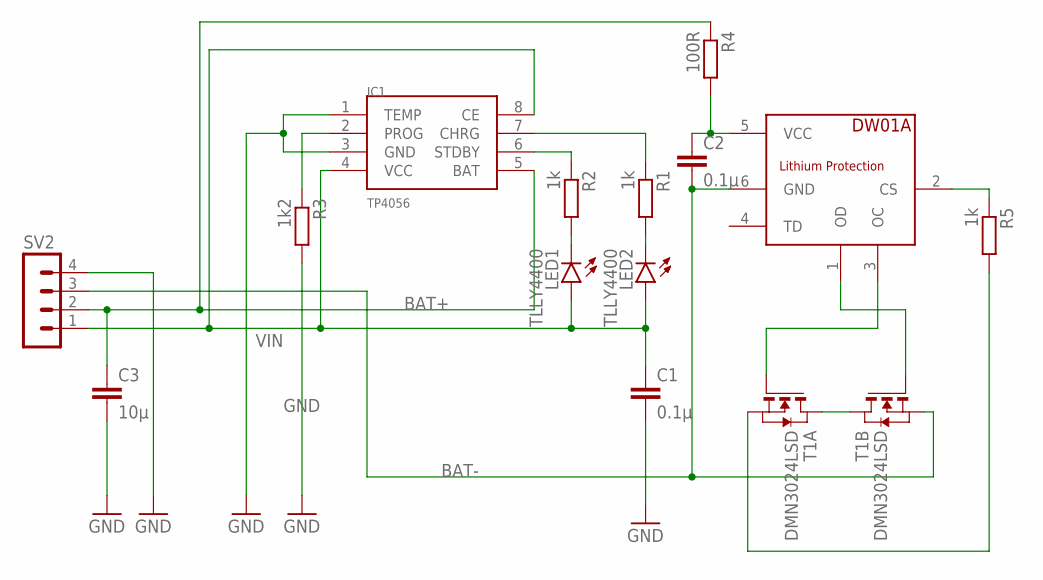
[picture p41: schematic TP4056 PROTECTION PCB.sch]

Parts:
C1, C2: 0.1µ; C1206
C3: 10µ; C1206
IC1: TP4056; SOP-8
LED1, LED2: TLLY4400; LED3MM
R1, R2, R5: 1k; R1206W
R3: 1k2; R1206W
R4: 100R; R1206W
SV2: MA04-1
T1: DMN3024LSD; TSSOP-8
U$1: DW01A; SOT23-6

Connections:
BAT+: C3.1, IC1.5 (BAT), R4.1, SV2.2
BAT-: C2.2, SV2.3, T1.6 (S), T1.7 (S), U$1.6 (GND)
GND: C1.2, C3.2, IC1.1 (TEMP), IC1.3 (GND), R3.2, SV2.4
unnamed: IC1.6 (STDBY), R2.1
unnamed: IC1.7 (CHRG), R1.1
unnamed: LED2.K (C), R1.2
unnamed: LED1.K (C), R2.2
unnamed: C2.1, R4.2, U$1.5 (VCC)
unnamed: R5.1, U$1.2 (CS)
unnamed: IC1.2 (PROG), R3.1
unnamed: T1.4 (G), U$1.3 (OC)
unnamed: T1.5 (G), U$1.1 (OD)
unnamed: T1.1 (D), T1.8 (D)
unnamed: R5.2, T1.2 (S), T1.3 (S)
VIN: C1.1, IC1.4 (VCC), IC1.8 (CE), LED1.A, LED2.A, SV2.1

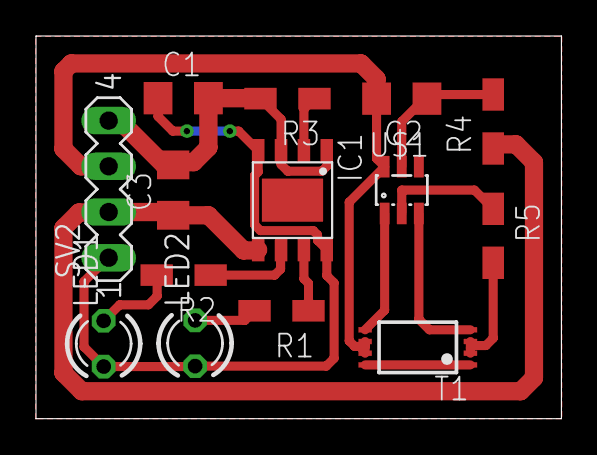
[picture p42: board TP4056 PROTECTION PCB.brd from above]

Board: 2 copper layers, 29.2 x 21.3 mm, 14 parts (0 on the bottom side), 15 nets.

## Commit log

2020-04-16 adding the full project into the git repo
    [Componentenlijst v0.1.csv, Prototype V0.2.brd, Prototype V0.2.sch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]
2020-05-22 adding the documentation here too
    [Componentenlijst v0.1.csv, Prototype V0.2.brd, Prototype V0.2.sch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]
